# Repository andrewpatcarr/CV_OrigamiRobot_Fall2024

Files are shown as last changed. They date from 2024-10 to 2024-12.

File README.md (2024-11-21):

CV_OrigamiRobot_Fall2024
---
---

Repository for Fall 2024 ME-400 (Special Problems for Advanced Undergraduates)
---

- Currently, focused on computer vision object detection and redesigning the origami worm robot.

- log.md has record of what I was doing on a particular day but was started about 2 weeks into quarter.

- setup.md has some setup information for RealSense 2 and YOLO

- Programming has some scripts for using RealSense, cv models, training and testing, and controller for robot

- CAD has the origami robot assembly, some other SolidWorks files, and STLs for 3D printing

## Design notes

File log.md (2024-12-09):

Logbook
---
---
12/08/2024
---
- created wiring diagram

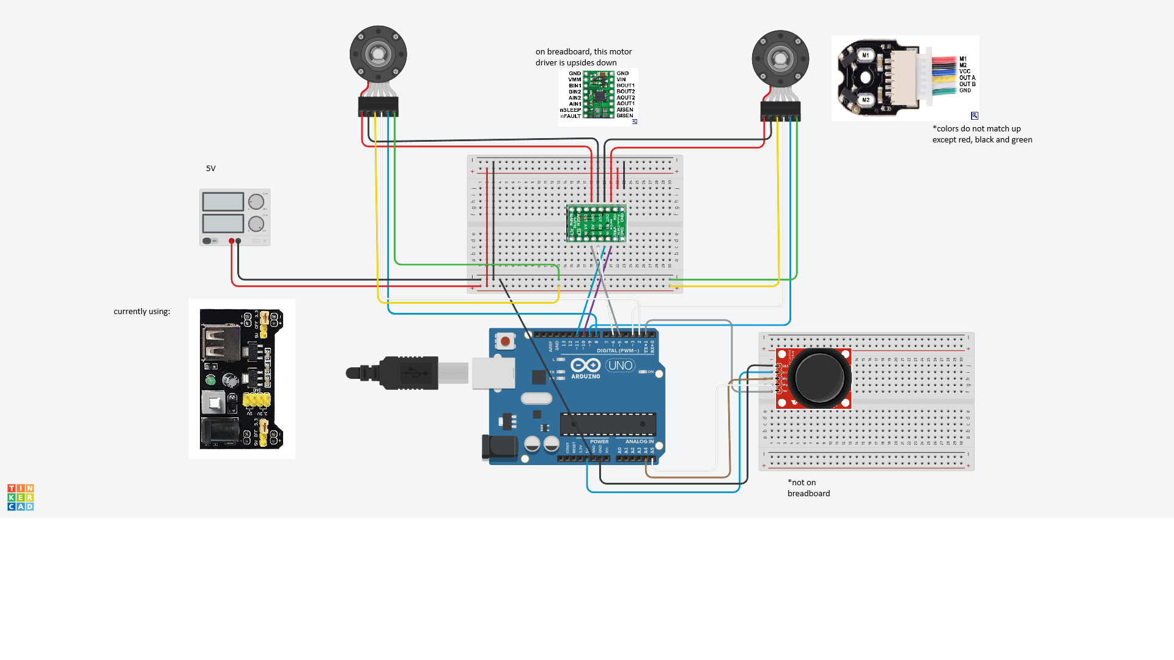
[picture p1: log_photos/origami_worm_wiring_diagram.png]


- created bill of materials
- wrote up assembly instructions
- pretty much done with [report/documentation](Origami%20Worm%20Robot%20Report%20and%20Documentation_FALL24.docx), might comment on main program

12/07/2024
---
- working on report/documentation
- had to fix some paths for images on log that got off because I reorganized some files
- tried new pad, pretty sure it is 25 degrees at 4 mm height. Works really well on carpet, going to try on rough outdoor surface

[video of robot on carpet](https://cpslo-my.sharepoint.com/:v:/g/personal/apcarr_calpoly_edu/EZ3gfSpz0YdHlWizx2pAg3gBb_xeV1YFyOWcL83Z5IEy0Q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)

- works on rough surface relatively well. Better than before for sure.

[video on standard garage concrete](https://cpslo-my.sharepoint.com/:v:/g/personal/apcarr_calpoly_edu/EVyeC1qBWZ9LjJJ2trlWG6QBVoEVjFBpGhsD8ZwvbOOz0Q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)

[video on rougher more irregular concrete](https://cpslo-my.sharepoint.com/:v:/g/personal/apcarr_calpoly_edu/EYgH6j8teHZAugXCq2LXksoB2CPt29aTcvvlFOFw1zrG9Q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)

- one thing i realized during testing: there is a balance between angle of the pad, the stiffness of the teeth, and the surface. This balance changes the performance. if the angle is very small, the teeth won't grab. if the angle is too large, the teeth won't grab. if the teeth are too weak, they will just fall down and not grab. If they are too stiff, they will not grab. A rougher surface seems to always be a good thing. Should try on sand paper to see

12/06/2024
---
- working on report/documentation

12/03/2024
---
- going to test more angled friction pads. Previous ones were at a 40 degree angle. New ones are 30 and 25. I am also make these longer. Previous were 3 mm tall, new ones are 4 and 4.5 mm tall.
- these should be less stiff and should deform and work closer to how we think they should
- the auto-orient showed me that I can print them standing up in a different way than I was thinking. I am putting 1 layer of raft because I feel it'll be unstable. Since I can print it this way, I am going to try 15 degrees. I had to reduce the amount of teeth from 6 to 5 for this.

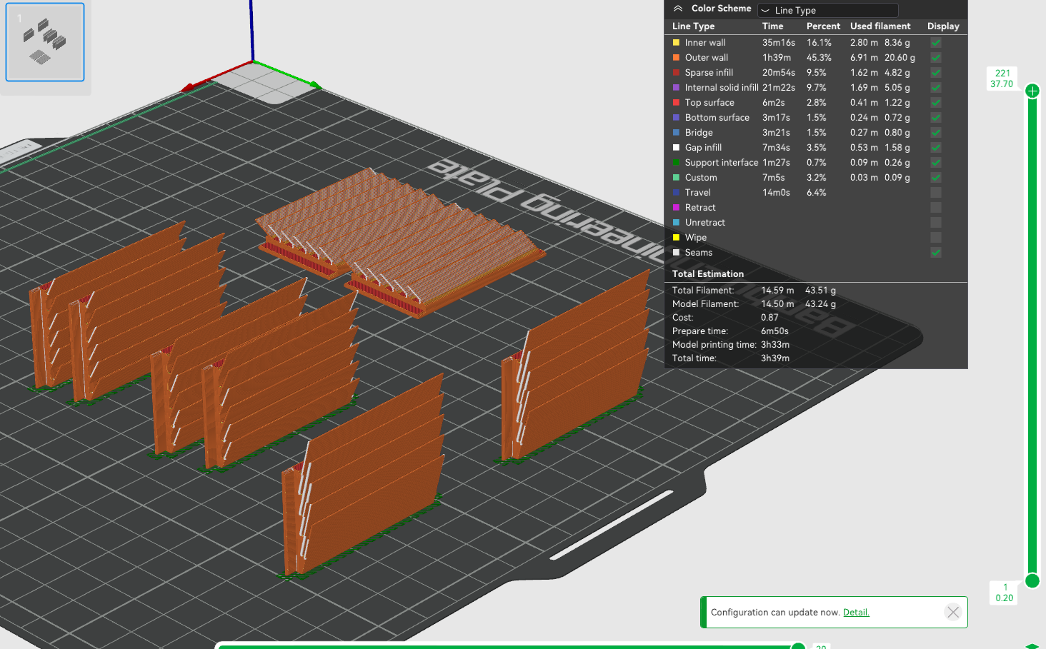
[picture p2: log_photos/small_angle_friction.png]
small_angle_friction


11/28/2024
---
- from last meeting, motion seems to work better with short and fast compression cycles. This is when the robot sits more flat but has torques curling the robot into the ground.
- The robot often gets stuck on one pad, but a max compression can sometimes set it free
- this [paper](https://ieeexplore.ieee.org/abstract/document/6266749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)
uses a single leg friction pad similar to our design. I think we could use something similar with longer legs as they will be much flexible and can deform how we want. 
- our motion is called peristaltic
- more worm angle seems to be cancelled out with less friction pad angle. So with a very large worm angle, we could have less worm angle and vice versa. Depending if we want less caterpillar like motion
- [OSCAR](https://www.ideals.illinois.edu/items/118254) uses a small locking wheel to get directional movement

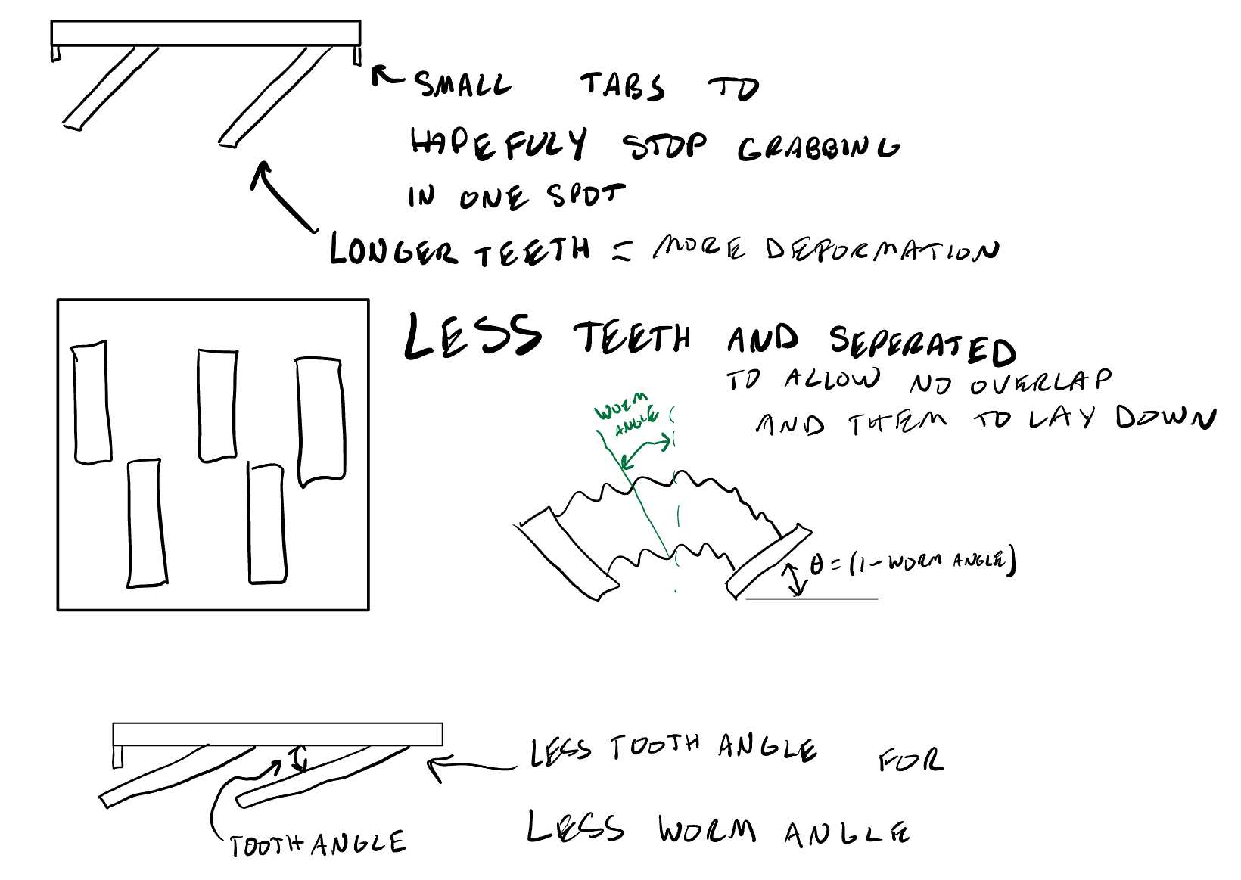
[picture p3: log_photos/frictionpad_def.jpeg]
frictionpad_def


11/20/2024
---
- new controller works very good, normal compression and decompression works smoothly. The controller also makes it easy to adjust one motor on the fly which also allows turning motion. It is up to the standard to complete reliable tests.
- tested it outside again, worked about the same as before --> not well. The surface was somewhat uneven but it looked more like the friction pads were not working as designed. The robot being so light allows the wires to make some impact. I tried to reduce it as much as possible but it is hard with stiff wires.
- I tried lowering the anchor point of the tether, and it did not make much of a difference. The friction pads definetly work in creating friction but one pad dominates and won't move either way. Or the pads will be at a similar friction force which makes both sides slide during compression.

Current motion cases:

1. compression --> both slip --> decompression --> one holds slips slightly less than other --> very small amount of forward displacement
2. compression --> one holds, other slips --> decompression --> same one holds, same one slips --> no motion

I see two possibilities for these problems:
1. theoretically sound for forward motion but very hard to create in the field
2. fundamentally and theoretically flawed for forward motion

- Directional friction is sound so I think it is likely that this would work if perfectly implemented, but is just very difficult to mitigate all the negative factors
- For the gecko pads, the implementation and overall movement may need to change. Similar to how an inch worm moves, a lifting, moving forward then planting approach would be ideal. It will be hard to actuate and move one side at a time. We don't have a way to only move one pad a time without directional friction.
- controller with no delay does not function. I am pretty sure this is do limitations of the motor driver. 

11/18/2024
---
- wrote new velocity control as shown in flow diagram [origami_joystick_control_DC_vel.ino](Programming/Arduino/origami_joystick_control_DC_vel/origami_joystick_control_DC_vel.ino)

11/17/2024
---
- Created flow diagrams for current control method (positionally) and for possible new method (velocity with alignment checking). Also created a flow diagram of how the x,y is decoded for straight motion and turning.

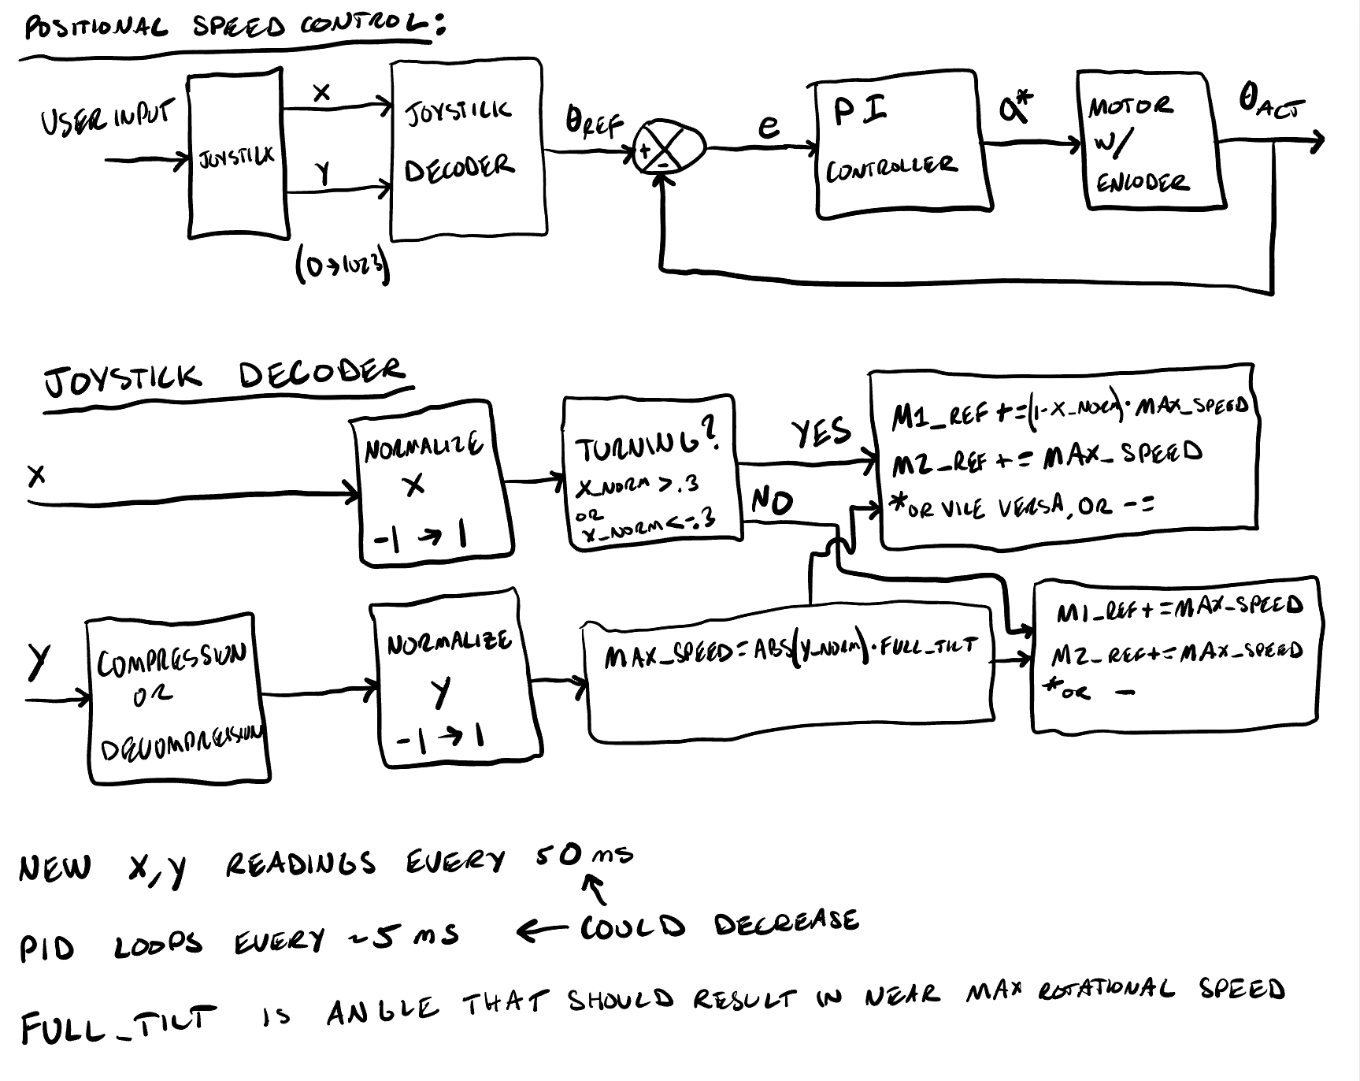
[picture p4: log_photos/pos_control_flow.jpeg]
pos_control_flow

vel_control_flow
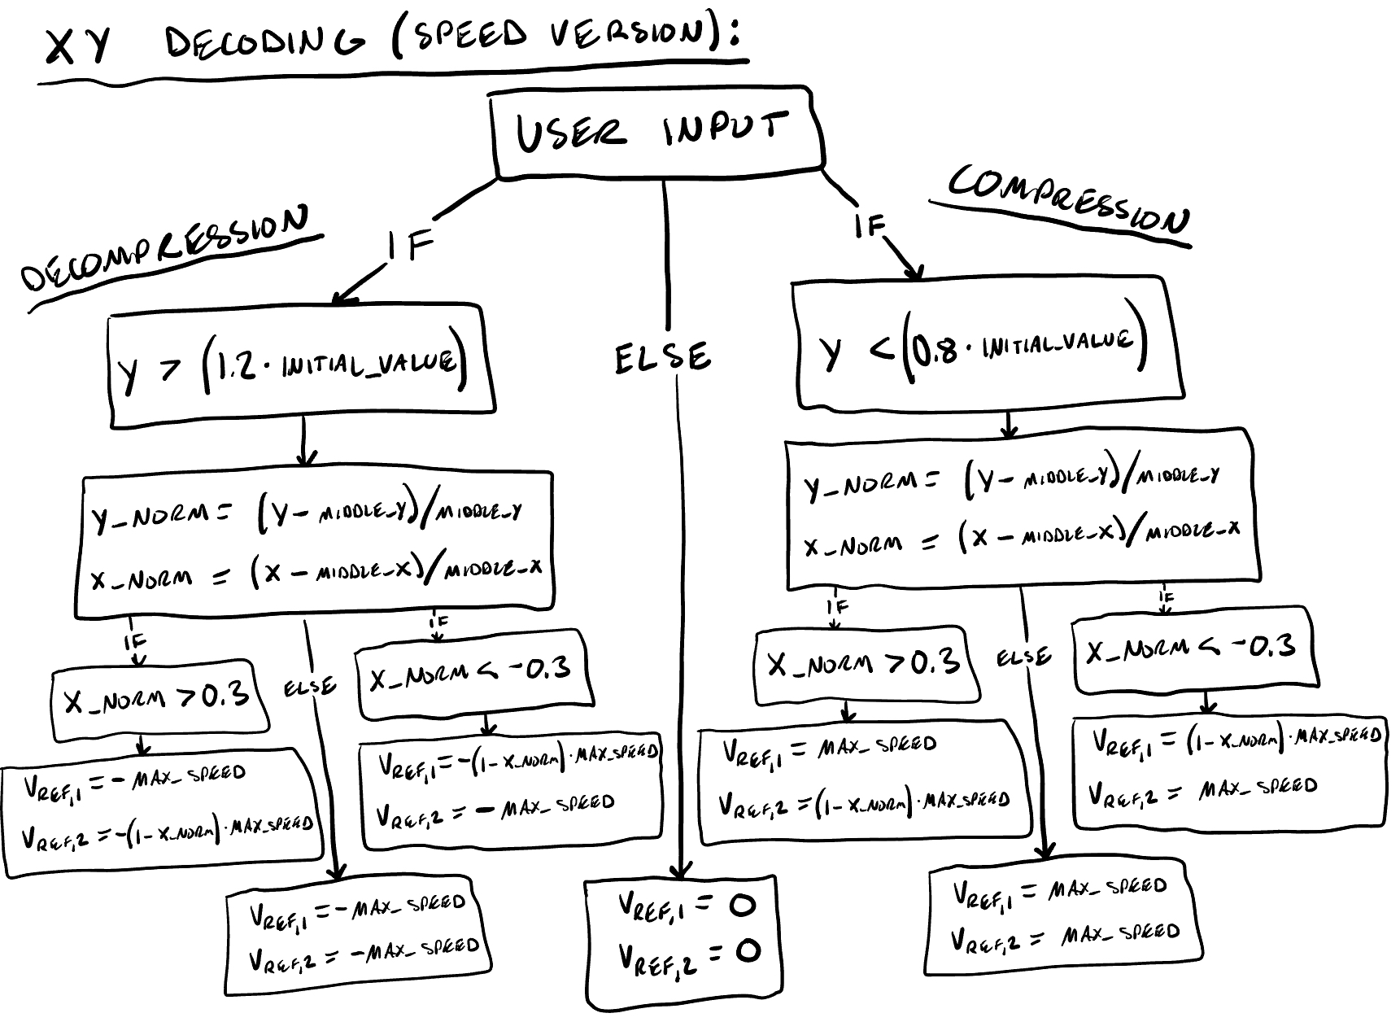
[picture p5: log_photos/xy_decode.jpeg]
xy_decode


11/15/2024
---
- worked out bugs enough for compression/decompression based on the joystick movements. Script for that is called origami_joystick_control_DC_pos.ino
- created new script for adjusting each motor independently based on joystick x and y

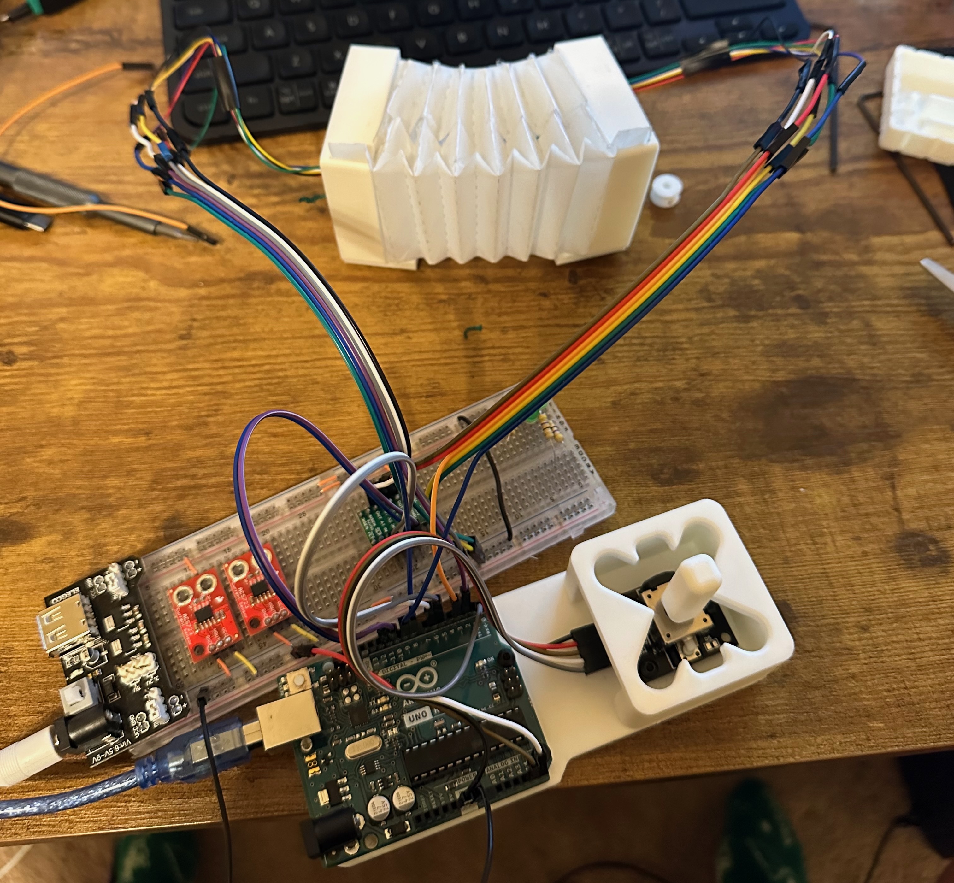
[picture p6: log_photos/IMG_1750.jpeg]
overview_photo

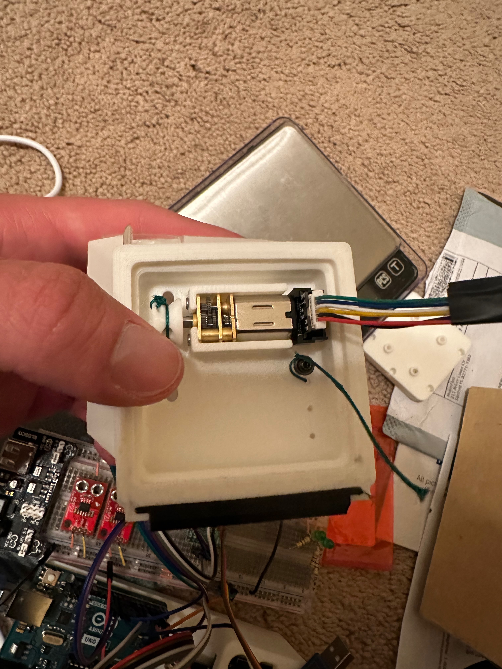
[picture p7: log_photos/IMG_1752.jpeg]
dc_motor_in


- going to test outside
- [video link](https://cpslo-my.sharepoint.com/:v:/g/personal/apcarr_calpoly_edu/EZbizppu2DRNnodf83J_MKYBdXKjzsVXct3wO4nJTWKWEA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). 
Increased worm angle seems to make movement possible again in the direction that the friction pads are designed for. The control is still not working great and you'll see it get off and jiggle during the movement. I think I need a combination of velocity and position PI control. Velocity for general movement and pos for reallignment after turning or if it gets off. 
- I think the next steps should be: get basics of controller working for reliable testing, try different worm angles, optimize friction pads

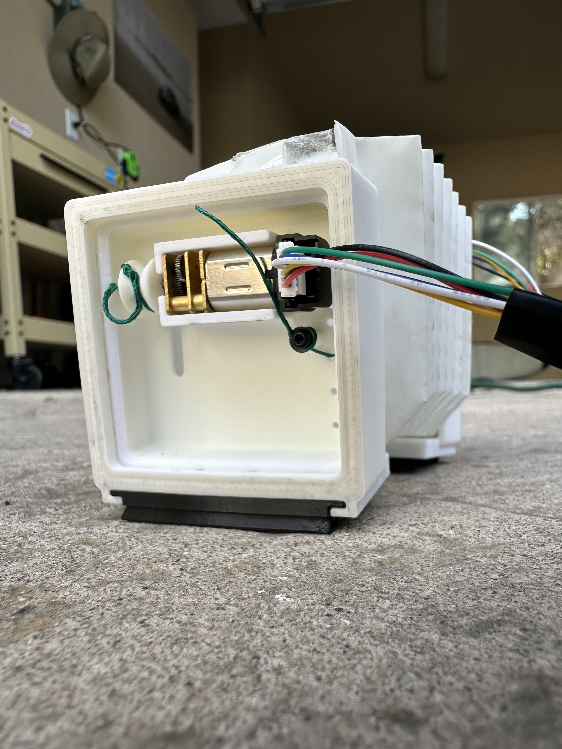
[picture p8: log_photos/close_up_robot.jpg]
close_up_robot


11/14/2024
---
- fully assembled rest of robot. Will update with more info tomorrow with some pictures. Worm motion is working better with lower hole attachment. Controller needs to be debugged for both motors and need to create a script for adjusting each motor independently
- new version is 97 grams

11/12/2024
---
- changed implementation on pid from velocity to position, differing speeds are made my adding degrees to the controllers setpoint then letting to try to go there for 20 ms. This method allows controller to control speed and direction well but needs to be adjusted and tuned. 
- I am going to add a feature that will align the motors back to the same angle position after a turn has been done or any time the x readout from joystick is zero. This will allow for ease recentering back to initial tension. 
- The controller needs to be tuned and the added degrees adjusted such that at normal full speed, the motors have space (in the form of PWM) to adjust and give power to one motor over the other in the case that one side of the robot has more spring force pushing back.
- made some final adjustments to the motor mount. Printing new ones that should be good to be mounted onto worm
- way to do line 2 above: function that checks if motors are out of sync, if compression then whatever motor is more negative in postion (or whatever the correct sign is). Then this function tells the motor to go to the other motors position and will continue to do so until gets within some amount of degrees. Then allow normal compression movement

11/11/2024
---
- soldered 22AWG wire onto JST wires so they could be pressed into breadboard and other connections



- wrote new control script for PID speed control with a motor class for control by the joystick, origami_joystick_control_DC
- The code has a class "DC_Motor" that has all the functions other than the encoder. Tried to do timing with interrupts at first but was getting some weird problems so decided to do it a less efficient but less complex way. 
- debugged most of code; encoder working properly; forward and reverse work alone; having a couple weird problems. One of them is that the joystick will make a motor turn correctly at first, but then it won't allow the other direction to turn. This problem is independent of direction and works both way. I tried to add a bunch of print statements but could not figure out why it is doing this. 
- took a little bit longer than expected to write all this code, but I think it will allow more performance once its working. May need to change PID method if the current velocity control method doesn't work. I could do it by calculating a small step in postion, then using a postion PID to go to that step in a constant amount of time so bigger position step will be more speed.

11/10/2024
---
- first try at motor mount makes me think that we may need to use the m1.6 screws for a better fitting. Going to try to find some or order some.
- soldered headers onto motor driver
- redesigned motor mount for m1.6s and easier assembly with pulley on

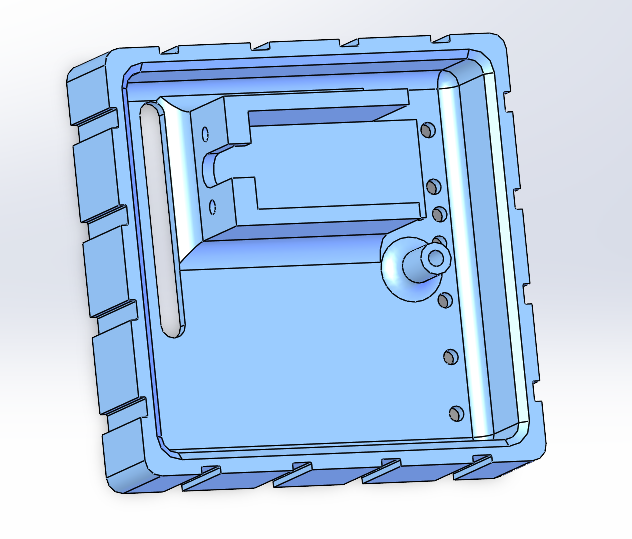
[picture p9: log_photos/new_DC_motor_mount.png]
new_DC_motor_mount


- designed new pulley for DC motor shaft

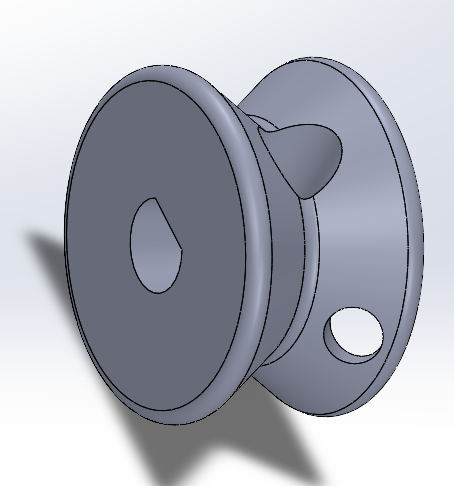
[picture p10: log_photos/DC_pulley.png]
DC_pulley


- fixed joystick/arduino board as was too tightly spaced
- received the JST SH connectors for motors
- printing all new components to test. Need to write new script for PID speed control of the robot to start. Might do some loop code once motion is working well.

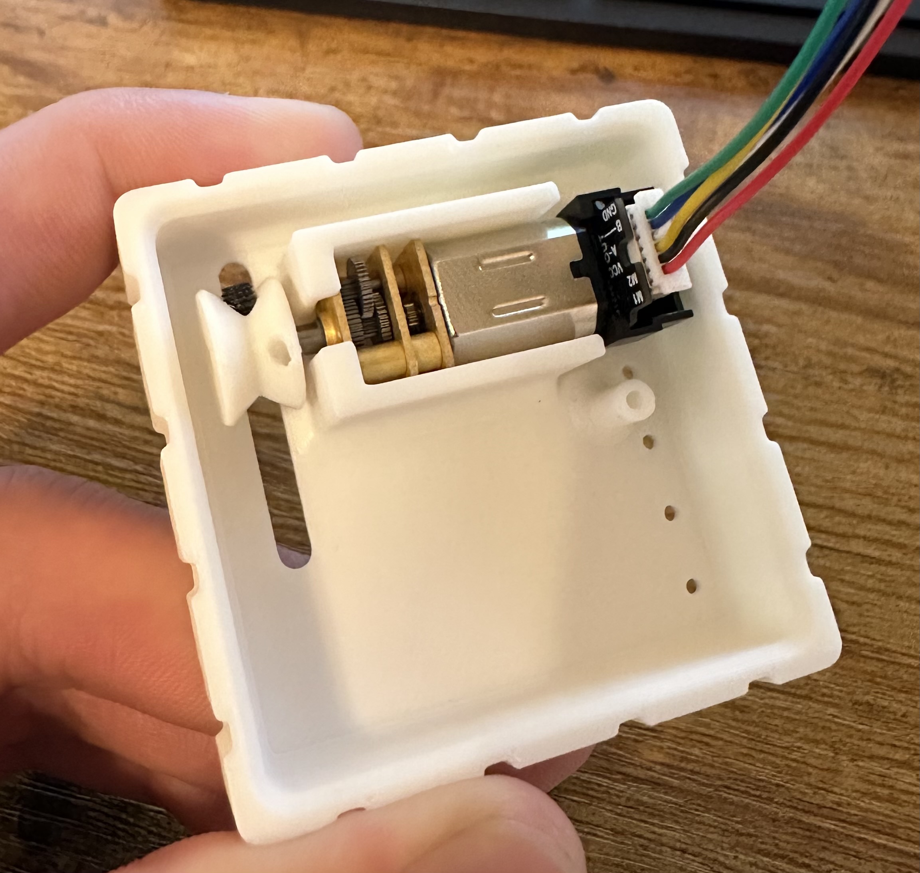
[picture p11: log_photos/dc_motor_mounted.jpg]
dc_motor_mounted


11/8/2024
---
- Last night, tested a bunch of new designs, thinner, thinnest and supersliced, which all did not work well. Although they did confirm that they are more frictioness than stiffplastic along so I think there needs to be a geometery that gets the friction pad out of the way rather than having a pure differential in friction.
- Here is the initial drawing idea: 

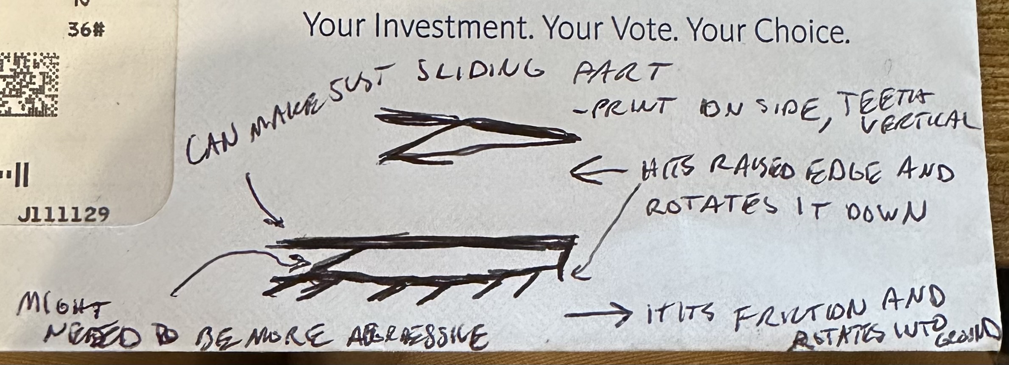
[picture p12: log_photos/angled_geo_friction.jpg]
angled_geo_friction


- And here is an initial solidworks creation of the geometry, but I think changes need to be made for it to work. The friction pad would be put on the left top surface:

angled_friction

- I want to try to create an extreme version of the supersliced (bunch of feet one) that has 1 mm feet and with stronger angles to replicate a form of backcountry ski skins
- Also, tried training for 50 epochs with data set and based on initial look into the data, it does not seem to have worked any better but did level off. Need to look more into it.
- [insert train 12 data and discussion]
- Designed a DC motor mount without screws, discovered it had m1.6s after and don't have any. If this idea doesn't work then I will get some screws. Going to print and test. 

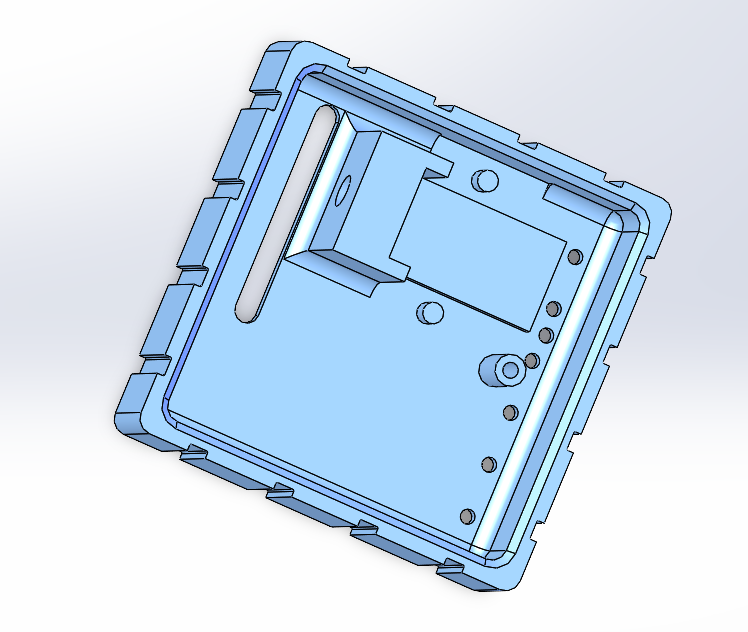
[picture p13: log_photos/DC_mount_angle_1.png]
DC_mount_angle_1

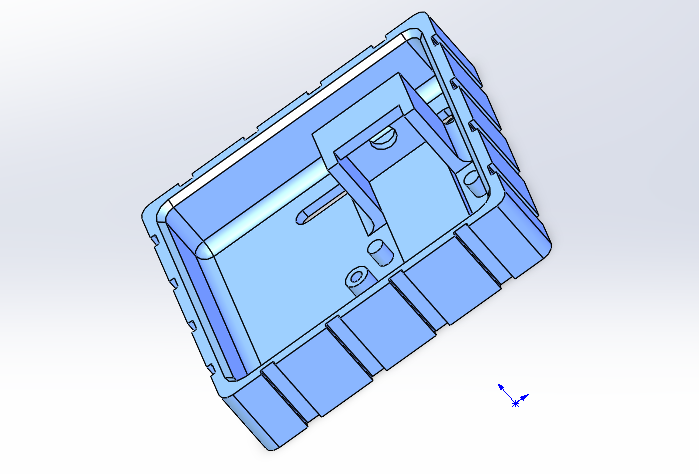
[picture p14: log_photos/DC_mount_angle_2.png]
DC_mount_angle_2

DC_clamp

- created a board that integrates joystick and arduino

11/6/2024
---
- drying the spool of tpu and going to print some new friction pads to try out
- got a pulley to work again, printed at .12 mm layer height; I'm pretty sure this means more precision on the teeth of the pulley
- read [research article](https://www.researchgate.net/profile/Kazim-Raza-5/publication/339640242_Fast_and_Accurate_Fish_Detection_Design_with_Improved_YOLO-v3_Model_and_Transfer_Learning/lin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)
but did not find much on how they did their transfer learning. It could have gone over my head, but it seems they just talked about the uses of it for this application. Here is a snippet from the short transfer learning section:

t_learning_snippet

- however, I did find that they trained their successful detection model for 100 epochs. I only trained for 10, and the training data makes it look like it was still steadily improving, but needed much more time. I think I will train it on the school computer for 50 epochs and see how that changes things
- going to look at more research papers to try to find some specifics on how they are implementing transfer learning
- started with brain tumor yolo-based model with transfer learning, but didn't say how they did it. They referenced [Deep Convolutional Neural Networks for Computer-Aided Detection: CNN Architectures, Dataset Characteristics and Transfer Learning](https://ieeexplore.ieee.org/document/7404017) (not on YOLO models) which mentions that they used smaller learning rates for all the CNN layers except the last. They say that "last fully-connected layer is random initialized and freshly trained, in order to accommodate the new object categories in our CADe applications"
 and its learning rate is kept at the original. They referenced [CNN Features off-the-shelf: an Astounding Baseline for Recognition](https://www.cv-foundation.org//openaccess/content_cvpr_workshops_2014/W15/papers/Razavian_CNN_Features_Off-the-Shelf_2014_CVPR_paper.pdf) for their method but they did not focus on object detection and were not using YOLO-based models.
- the default epochs for yolo training is set at 100, definitely think our model needs to be trained for more epochs
- from the last training, here are some plots showing the progression of our mAP50 and mAP50-95 (mean average precision for different levels of correctness) which show that it hadn't flattened out yet

train10_mAP_plots

- outside test with initial friction pads which are pretty thick: [link](https://cpslo-my.sharepoint.com/:v:/g/personal/apcarr_calpoly_edu/Ea4VjNevzMZMiXy5tFDmahABc4tGWjPi51OIGT4sImdVfA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)
. The speed controlled servos are battling different strengths of spring force and don't compress at same rate without manual adjustment to scales. DC motors will fix that problem. The friction pad in use does not flex much and did not work well. I'm hoping some of the new designs will work better which are all thinner
- doing a quick static loading study on solidworks to see how the model will deflect which I think is key to friction pad success. One side is approximately 50 grams. Didn't set up fixtures correctly, going to try again another time.

11/5/2024
---
- created some new friction pad ideas, going to print later and test if i can get a pulley to work on the servo.
- two are thinner versions of original. The rest of them are cut out designs based on the thinner version of current

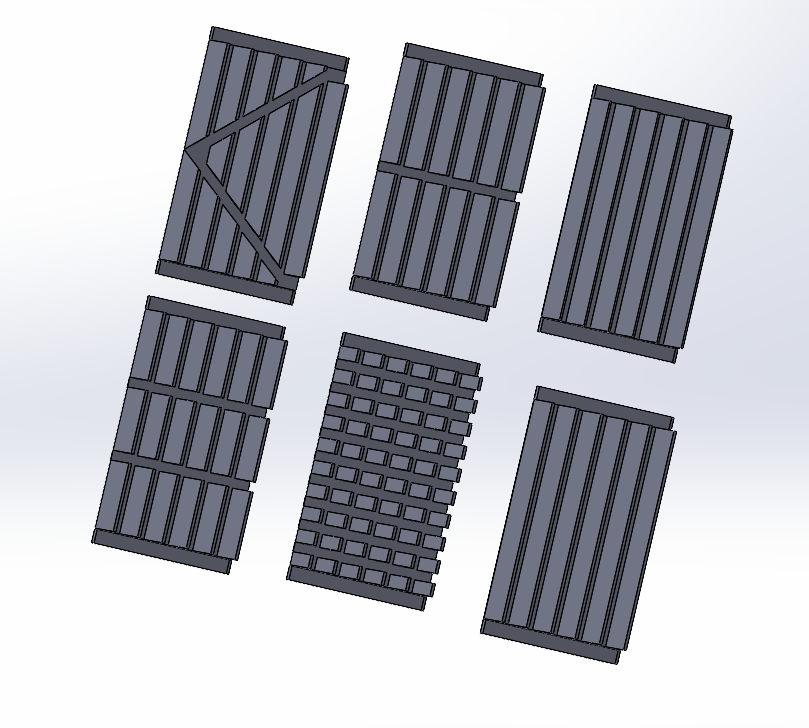
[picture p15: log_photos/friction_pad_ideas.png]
friction_pad_ideas


11/3/2024
---
- 10 epochs took 9.31 hours. Inference time went down significantly from 1 epoch train (~90 ms to 5.8 ms). As seen in table, the model only detecting robot arm in one of the photos. Most likely due to incomplete data and maybe not enough angles. Performance of other objects was decent considering this is far less images than full COCO dataset
- cleaned up wiring on arduino and current sensor as much as possible
- found a joystick module and created new script to control the worm using it. It allows pure compression/decompression as well as turning commands. Should make it much easier to test and use
- Looks like this: 

joystick_module
- going to design a base for joystick module and top so its easier to use and control
- base and joystick top created and being printed now
- made this joystick transmission thing so its easier to go dead straight and to a pure turn

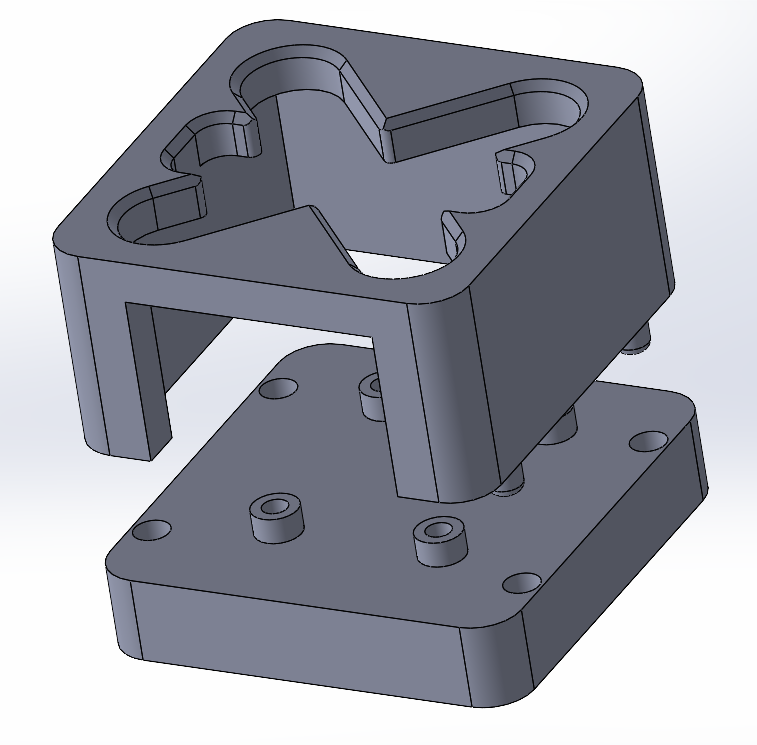
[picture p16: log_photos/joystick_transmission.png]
joystick_transmission


- transmission looks cooler than it actually works but still is good for guiding turn:

real_life_joystick_assem

Video of test:

[joystick_assem_test](https://cpslo-my.sharepoint.com/:v:/g/personal/apcarr_calpoly_edu/EaTgc_oRwHBKrTsXxgcHwpsBTS4aR1mzuO3mRuU0t0Zwog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)

<!DOCTYPE html>
<html lang="en">
<head>
    <meta charset="UTF-8">
    <meta name="viewport" content="width=device-width, initial-scale=1.0">
    <title>Image Comparison Table</title>
    <style>
        table {
            width: 100%;
            border-collapse: collapse;
        }
        th, td {
            border: 3px solid #ddd;
            padding: 8px;
            text-align: center;
        }
        th {
            background-color: #f2f2f2;
        }
        img {
            width: 300px; /* Adjust size as needed */
            height: auto;
        }
        .row-header {
            background-color: #f9f9f9;
            font-weight: bold;
        }
    </style>
</head>
<body>

<h2>Model Image Comparison</h2>

<table>
    <thead>
        <tr>
            <th>Image #</th> <!-- Empty cell for top-left corner -->
            <th>11s</th>
            <th>11n</th>
            <th>4 class custom</th>
            <th>COCO+Robotic-arm off 11s</th>
        </tr>
    </thead>
    <tbody>
        <tr>
            <th>1</th>
            <td>Model 1 - Image 1</td>
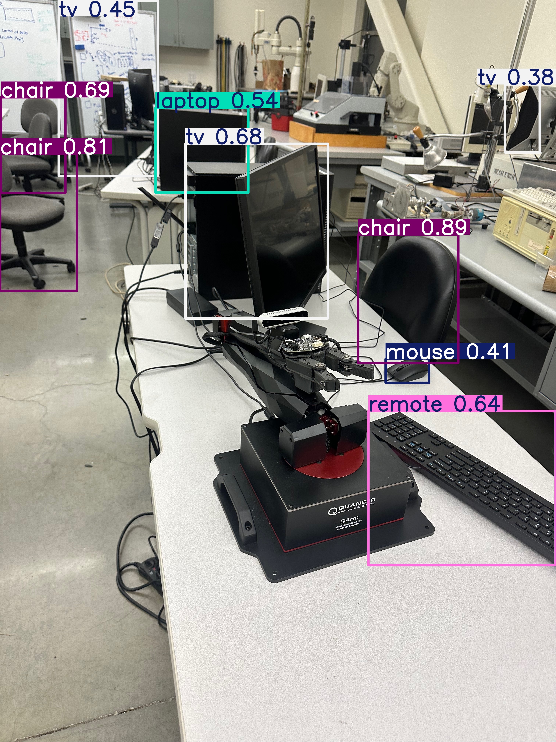
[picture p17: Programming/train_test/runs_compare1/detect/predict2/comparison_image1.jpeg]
Model 2 - Image 1
            <td></td>
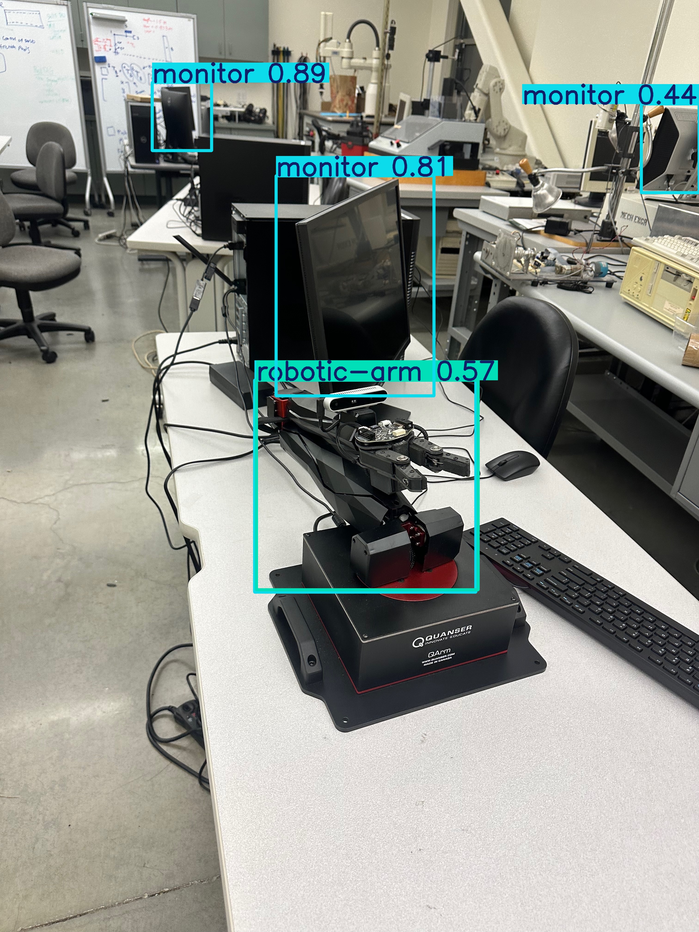
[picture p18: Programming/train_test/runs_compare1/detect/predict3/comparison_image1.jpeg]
Model 3 - Image 1
            <td></td>
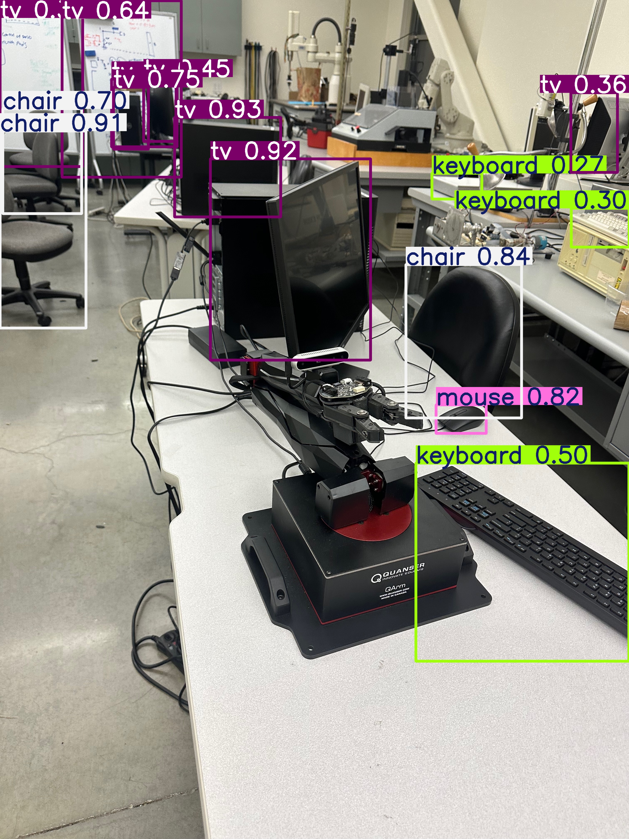
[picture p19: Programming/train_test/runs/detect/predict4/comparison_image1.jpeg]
Model 4 - Image 1
            <td></td>
        </tr>
        <tr>
            <th>2</th>
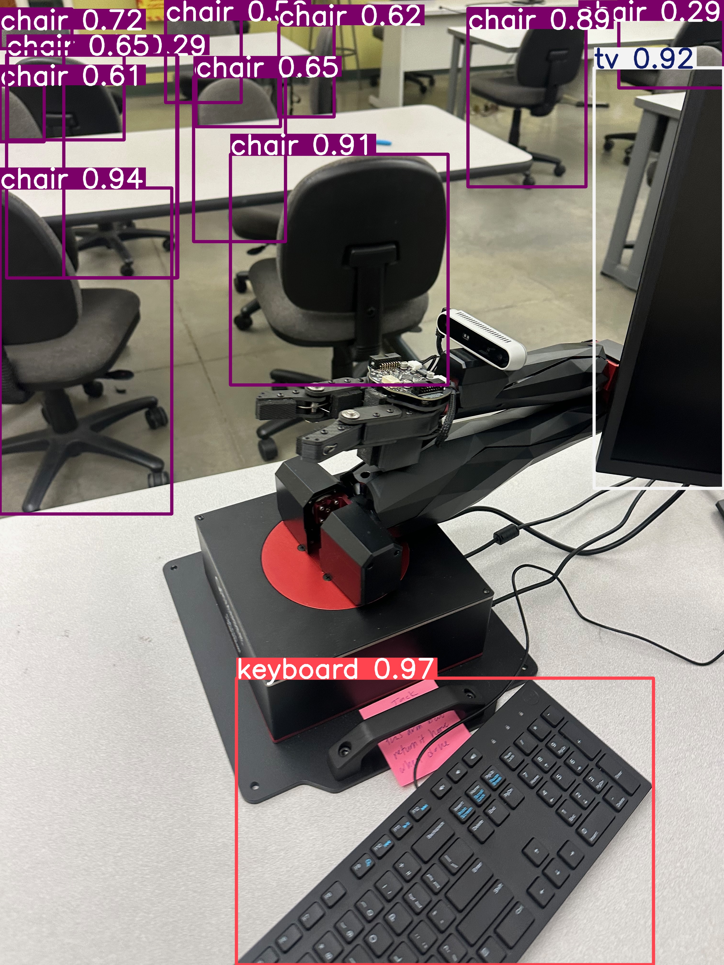
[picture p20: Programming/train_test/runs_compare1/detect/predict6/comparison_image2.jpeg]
Model 1 - Image 2
            <td></td>
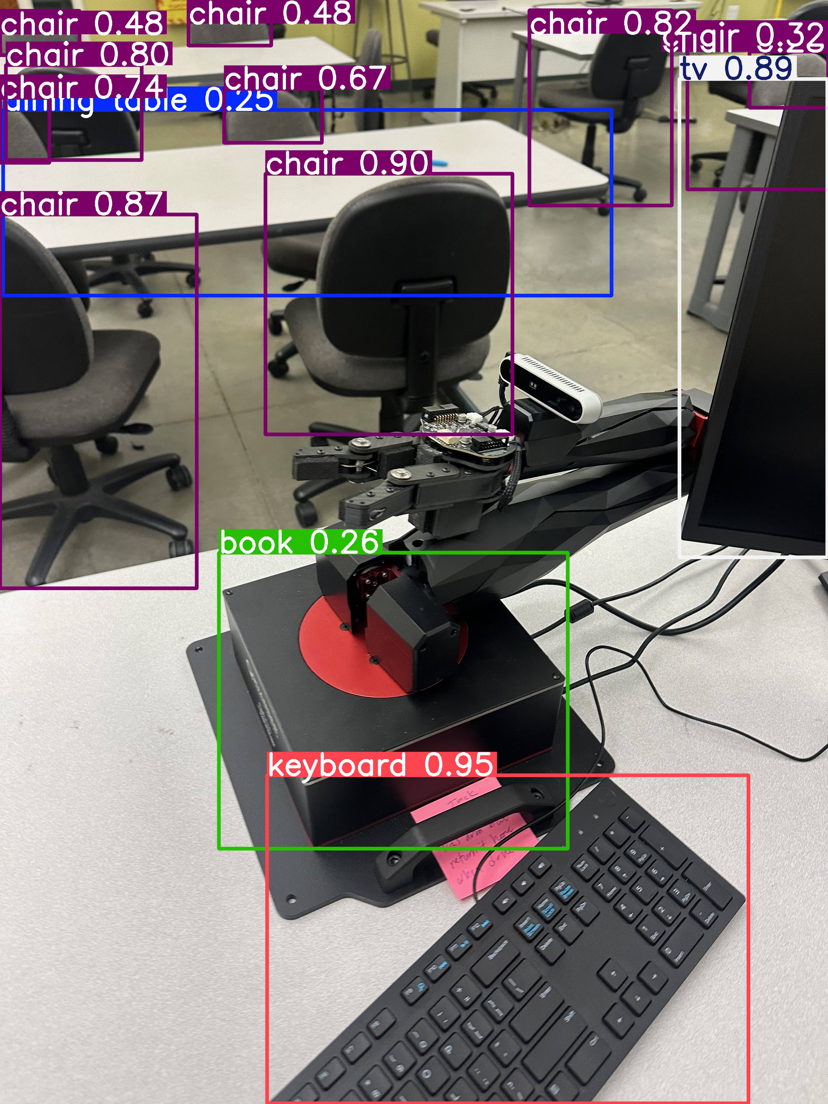
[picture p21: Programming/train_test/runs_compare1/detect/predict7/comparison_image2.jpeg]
Model 2 - Image 2
            <td></td>
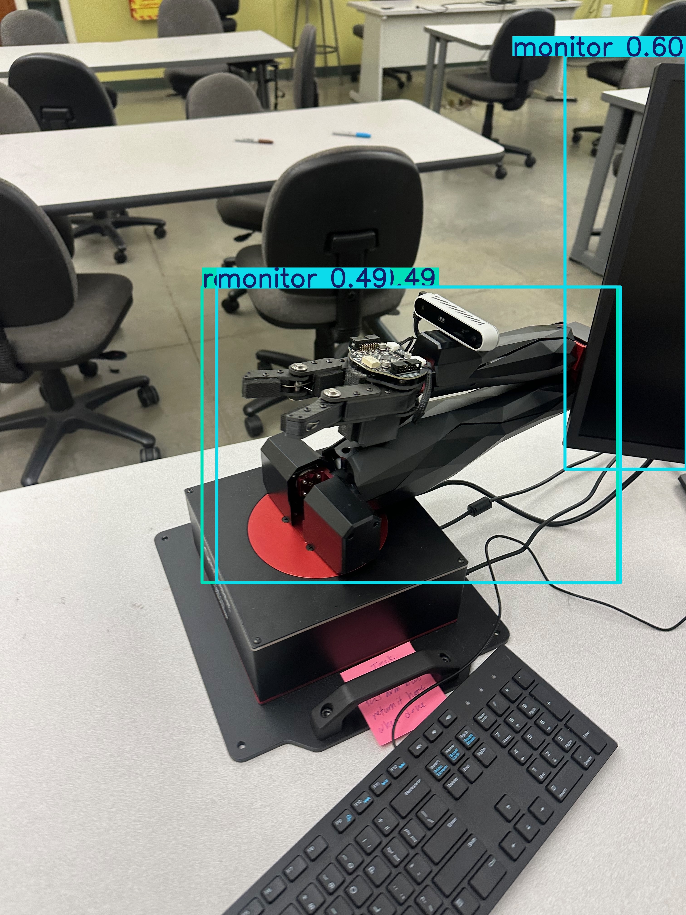
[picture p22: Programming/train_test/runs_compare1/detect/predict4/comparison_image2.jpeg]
Model 3 - Image 2
            <td></td>
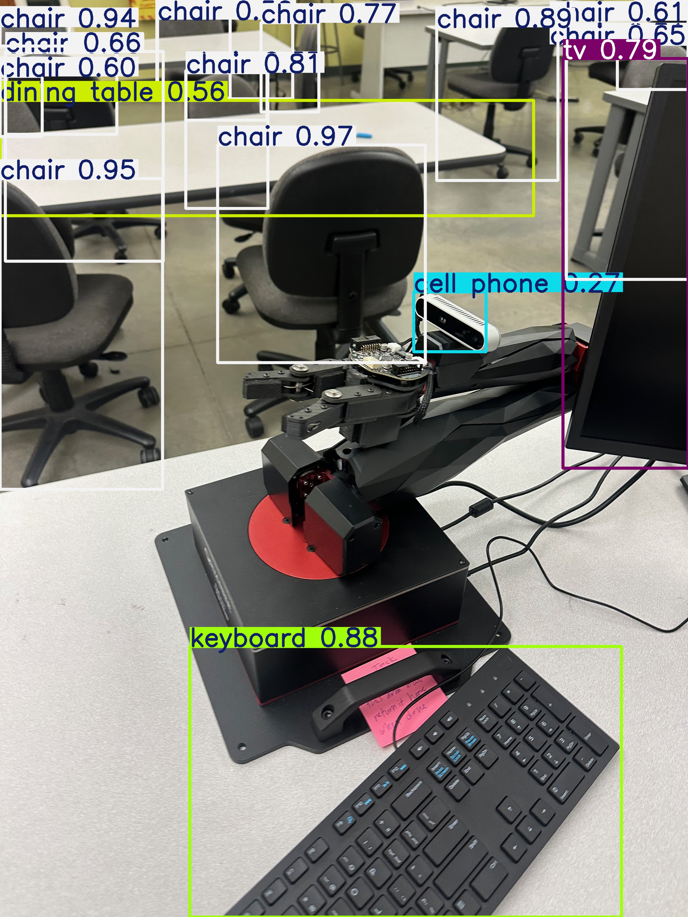
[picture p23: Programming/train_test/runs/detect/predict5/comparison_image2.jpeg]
Model 4 - Image 2
            <td></td>
        </tr>
        <tr>
            <th>3</th>
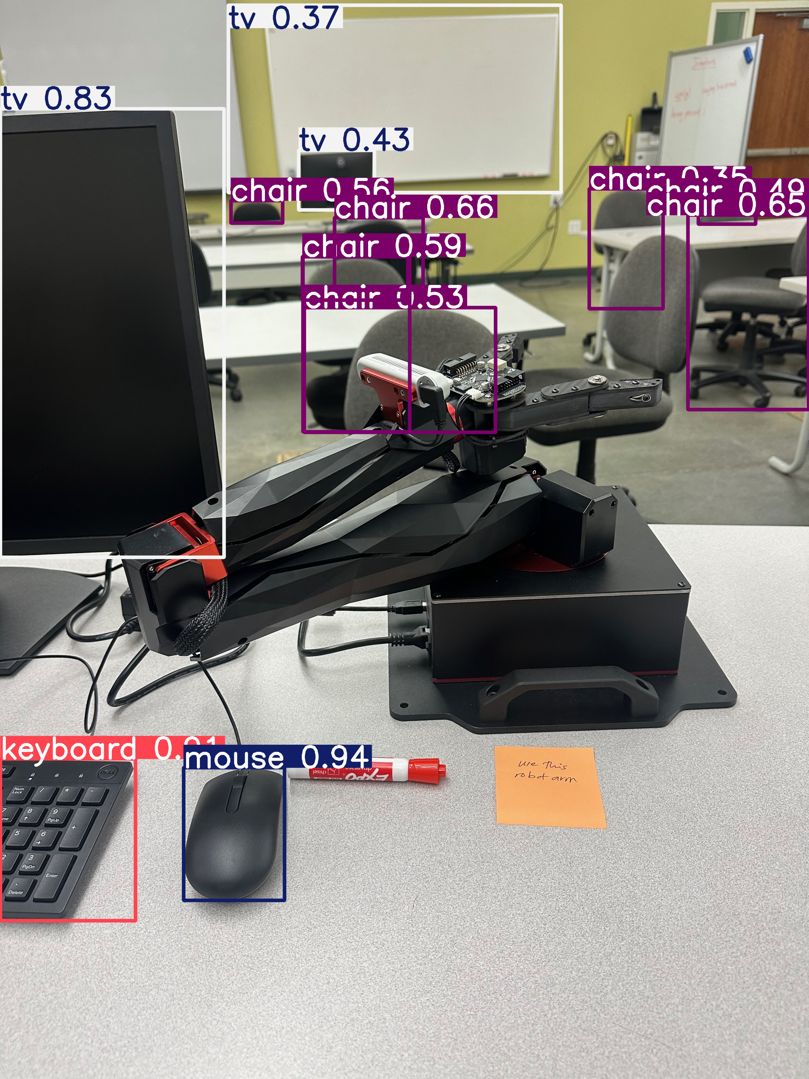
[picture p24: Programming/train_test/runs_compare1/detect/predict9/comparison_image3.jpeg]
Model 1 - Image 2
            <td></td>
            <td>Model 2 - Image 2</td>
            <td>Model 3 - Image 2</td>
            <td>Model 4 - Image 2</td> 
        </tr>
    </tbody>
</table>

</body>
</html>

11/2/2024
---
CV stuff
- going to label new robotic-arm photos to finish rest of the dataset; added 101 photos with robotic-arms in them
- new dataset has 81 classes, 20413 photos for training, 1982 for validation, 990 for testing after augmentation
- going to train model from scratch first, then freeze train with same dataset to get an idea of time and quality differences
- ran a training for only 1 epoch to get a sense of how long it will take to train, and how good 1 epoch will train the set. Looks like its going to take roughly an hour. At home, there are 1274 iterations per epoch at 8.5G of GPU mem.
- with 1 epoch (train9), it did not recognize the robotic-arm, I'm going to train for 10 epochs overnight
- it says this when the training starts, so I think it is automatically doing freeze training when a model is inputted as part of the train command:

freeze_training_maybe

Only referring to the top two lines in screenshot

this is the code I used for this

    yolo task=detect mode=train model=yolo11s.pt data=COCO_robotic_trainingset\data.yaml epochs=10 imgsz=640 device=0

10/27/2024
---
CV Stuff (since a lot written about both sides of the project today)
- coco dataset upload failed on roboflow, need to delete whole project to upload more photos with free plan
- Tested friction pad with robot on carpet, worked for a second but then got stuck with the back sliding back and forth. The pulleys keep slipping, I think it would be worth it to switch to DC motors. Also, thought of an update to the pulley so that the thread won't come off when there is not tension. Going to make it enclosed where the pulley is
- Uploaded dataset to roboflow again, but it looks like they don't have the correct annotations again. Uploading them and going to see if they do after uploading. If not, might need to find a different dataset. Either way, I am going to try to freeze train with other dataset with limited classes and see if it keeps COCO classes
- Annotations did not work
- Did some more research into freeze training on newer models of YOLO. Most of the information on freezing layers and retraining final layers was for older outdated YOLO models. Now that you can just pip install ultralytics and have everything you need to use new YOLO models, its different to freeze layers and train. Going to keep looking into it
- in the "[train](https://docs.ultralytics.com/modes/train/#train-settings)" documentation, there is an argument "freeze" that freezes the first N layers of the model by index. I should be able to use this for our purpose, just need a good dataset
- looking at this [discussion](https://github.com/orgs/ultralytics/discussions/3862), it should be possible to do freeze and then train. One ultralytics moderator said that it is not completely necessary to freeze the backbone to add classes to coco. If i can get a good coco 10k or 5k dataset, I should be able to try both of these. Some of it is still quite confusing on how to actually do any of this successfully.
- found [this](https://www.kaggle.com/datasets/bardiaardakanian/mmsample?resource=download) 5k dataset which (if it works), should be good enough for testing if freezing works and is useful
- Going to make a new dataset of robotic-arm oriented photos and label with COCO labels and then robotic-arm

Worm Robot Stuff
- printing new pla pulley; if doesn't work, I'm going to look into small geared dc motors with encoders
- pla pulley had better teeth connection this time, used a different, longer m2 bolt that threads in better and locks better; going to test movement
- put dataset into roboflow, looks like it has labels this time, but it ended up being 10,000 images because there were 5000 for train and 5000 for validation. To add robotic arm photos, I'll need to delete some of the images unless we upgrade our roboflow plan.
- Looking at small geared dc motors, need to be <40mm in full length to fit. Center of pulley needs to be around 37 mm from far side of servo mount. This [one](https://www.amazon.com/dp/B07FVRL4SW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) is a possibility.
  The one linked is 500 rpm  with .15kg-cm rated torque. According to [this](https://www.amazon.com/FEETECH-Continuous-Rotation-Helicopter-Airplane/dp/B097SZQ4CH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), the current servos only provide stall torque which is 1.5 kg-cm.
- Thinking if we are to get better motors, we should also try to maximize performance for future changes and use cases
- Quick calc for required torque with pulley diameter: 

motor_torque_calc

(if this is too small, it is [here](log_photos/motor_torque_calc.jpg))

- after that calc, the motor does not need anything close to 500 rpm. Under 60 will be good (future extra speed); should allow for a very high torque but small motor
- there are many good dc motor options (like [this](https://www.amazon.com/Hilitand-Brush-Geared-1218GE%E2%80%91N20-Reduction/dp/B08LLCL97S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), but getting one with an encoder is difficult. May be able to use an optical speed sensor but could be difficult to incorporate
- [This](https://www.amazon.com/dp/B07N18S3M3/ref=twister_B0BPM11WG6?_encoding=UTF8&th=1) looks good, but has no information on torque, pps, or dimensions so pretty sketchy
- A potentiometer type encoder could work but unsure if something like [this](https://www.amazon.com/uxcell-Encoder-Digital-Potentiometer-D-Shaft/dp/B07R9LSWTP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) is continous rotation or not
- Pololu makes high quality motors, used some for internship. This [one](https://www.pololu.com/product/5147) is geared with an encoder. It has a no-load speed of 73 rpm and a stall torque of 2.4 kg-cm. They are more expensive than other ones ($26). This is one of the medium power options. They have some that operate at higher power and lower power. The motor will fit well in the casing. 
- There will be 6 wires for each motor then which will impact the performance if they are going directly to the arduino. A possible solution would be to use one chip to do all the work with the encoders and just send an angle value to the main microcontroller. 
- Idea for fully contained, WiFi enabled future design for robot: 

origami_concept

- ideas for components within above design: [6V battery](https://www.duracell.com/en-us/product/ultra-lithium-223-battery/) that will fit, [Pi Pico](https://www.amazon.com/Raspberry-Pre-Soldered-Microcontroller-Development-Dual-Core/dp/B08X7HN2VG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) that will fit, 
- above design does not have motor drivers; they would fit near each motor relatively easily or even just one for both on the side with the pico. A dual motor driver like [this](https://www.robotshop.com/products/pololu-drv8833-motor-controller-2130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) would be good
- custom pcb would be ideal in the far future of iterations
- Improving the strength, ability to control, and quality of the design and prototype is important so that multiple techniques for increasing performance can be tried (ex. varying speed of compression, controlling differential tension).

10/23/2024
---
- adjusted thickness of friction pad slider to 1.2 mm; tested and it was too thin; put it to 1.3 mm and tested; tight fit but still easy to get in, could be a hair too thin but for the strenfth of the servos and expected friction, it should be fine
- going to test on the arduino
- in the future, changing to dc motor with encoder, motor driver could increase performance drastically; especially for speed and accurate rotation
- in testing, one of the pulleys started to slip where the teeth connect. Going to try printing it out of nylon
- did some of a csu training i need to do
- nylon gear did not print accurately enough to have teeth; going to print another pla one for now
- 10k dataset uploaded to roboflow but none of the photos have annotations. Might need to reupload to roboflow again, cause it took a while and I went to sleep before
- going to get a test photo going, might get a better one from lab with many photos tomorrow

code used:

    yolo detect  predict model=yolo11n.pt source='"C:\Users\Andrew Carr\Downloads\CV_OrigamiRobot_Fall2024\Object Photos\comparison_image2.jpeg"'

10/21/2024
---
- all robot structure parts printed; assembled it from scratch in about 35 minutes; everything seems to be in right order
  
- the plastic threads of the servo horn screw seem to be stripped on one of the servo which is partly how I tighten the thread into place. If this reoccurs as a problem, I may need to redesign
- going to print the new tpu pads to see how they work/fit into mount

10/20/2024
---
- all parts printed, going to assemble robot
- when trying to put clamp on, discovered that I didn't change the outer diameter dimension of servo mount so did not work; fixed it and printing new one, which will be an hour
- tried to get smaller cocodataset but some of the options that were posted would not download for me; going to keep looking
- Tried to download from this [repo](https://github.com/nightrome/cocostuff10k?tab=readme-ov-file) which I think it legitamate but outdated
- trying to download from this [dataset ninja](https://datasetninja.com/cocostuff10k#download) but wasn't working in a similar way to the above repo but can install from a python package so trying that.
  Above did not work, python script showed I was missing package but I followed instructions on website and didn't mention anything about it
- Dataset ninja download for supervisely format dataset worked and Roboflow can take supervisely formatted files
- Uploading to roboflow but learned only allowed to have 10,000 total so have to get rid of about 300. Hopefully doesn't make some of the annotations not work. Looks like it might take a bit, roughly 4 hours
- another error on the position of the tabs of the servo mount. Confident I fixed this time by making assembly in solidworks of actual pieces instead of test pieces. Going to reprint
- fitment test looks like this: fitment_show
- this is what it looks like assembled in solid works (except servo is actually rotated 90deg so need to fix mates): assembled_1

10/19/2024
---
- Print failed last night, pretty sure it was a surface grip problem but so going to reglue and try again
- found an error on my pulley part that may have made the print fail; I changed a diameter that another was based on but didn't update other side
- new way for attaching thread to pulley works very well; struggling to print out the teeth good enough to properly attach to servo
- trying some smaller outer diameter of teeth section
- trying to download a smaller version of coco to try transfer learning based on this [tutorial](https://github.com/ultralytics/yolov5/issues/1314)
- need to combine custom dataset with new object; curious what will happen if i have more than one of the same class
- new outer tooth diameter worked, 4.7 mm. Pulley system seems like it will work well
- updated servo mount to be stronger and fit the servo better: new_servo_mount
- adding a screw into place method for tightening other side of thread to servo mount

10/18/2024
---
- original idea for friction pads did not work as intended, pulley printed was too tight of tolerances for hole and connection teeth
- some new ideas for both of those: put hole through center of pulley section so I can pull thread through and put screw in to lock it into place
- for the friction pad: Create a way to just slide it in but have the friction pad be extra thick so only friction pad part will interact with ground
- going to cad it up
- new pulley: new_pulley
- new friction pad mount on clamp: new_outclamp
- new friction pad, trying to make ridges stronger, and new clamp system: new_frictpad
- increased inner wall dimension on clamp to make it a little easier for it to clamp
- going to print and test

10/15/2024
---
- working on 3D printable servo horn pulley; found cad file of servo on internet; designed horn off of other shaft
- here's what the first edition looks like in solidworks, also cut out a slot so servo will sit properly
servo_pulley_one
- printer can do resolution pulley_print
10/14/2024
---
- went to lab to test and saw that the springs edges are not just squares,
  there is a flat fold sticking up on top right/left of the robot,
  will need to adjust design
- going to bring robot home so i can design things for it better
- though of better way to connect friction pads using the flexibility of tpu
- tpu friction pad print went well, much more flexible but maybe too much
- looking at windup system on the servo for cable, needs to be better and I have an idea in mind;
  I think its important that the mechanisms for the robot are well designed so that proper testing can happen,
  hard to trust results when many other factors could be affecting results.
- measuring mylar with verniers shows a thickness of 0.4mm; currently printing new version with slot but spacing might be too aggressive
- added new way of sliding friction pad into place, then realized that I could now have the friction pad be more centered under the mount;
  might increase friction and performance
- fit test worked with walls; pretty tight but gives it a much more stable feel and look; allows the origami spring to only act as spring and not interact with ground
fit_test_walls
- printing updated clamp and servo mount to reassemble robot; once this print is done, will print friction pad that will fit in new system

10/13/2024
---
- starting redesign of origami robot structure and friction pads, need other parts to function better to properly test and get better results
- going to try printing pads in tpu, also new idea for a one way leverage mechanism that will press into ground in one direction
- trying new way to connect spring to mount, basically a press fit piece that will go around normal one and press fit the spring in
- this might allow for better connection and integration of the friction pads
- getting weird error in solidworks that the piece can't face or plane but won't show me where so hard to fix. Part looks fine so going to ignore for now
- going to create test piece for testing fitment
- printing at home out of pla, about 30 min, some parts of design look a little thin, but we'll see
- going to get my tpu ready to go to try printing out of that, needs to be dried for 24 hours at 50 degC before I can print
- from looking at print, thicknesses and size of walls and teeth need to be increased
- looking at paper to try to find thickness of mylar, will probably need to go to lab to test properly, did not find thickness
- going to work on one way friction press mechanism
  new_friction_idea
- fit test worked pretty well, might need to try some different spacings, new version will be stiffer too
  paper_fit_test
- printing new version (larger teeth, thicker walls, filet on corner) and going to test with mylar spring, 32 min print, pla
- here's what the new clamp design looks like in solidworks new_clamp_solidworks
- new test piece did not fit together well, some parts were too tight, giving it more clearance and going to try again
- pretty sure problem was that the extra clearance given was only going to one side since location of tooth dimension was on one side, 
  so adjusted location such that it has .2 mm clearance on each side
- giving .2 mm clearance on each side of tooth, .4 mm at top of tooth; 
  outer diam of inner clamp is 52.78 mm, inner diam of outer clamp is 53.5 mm ~~ .75/2 == .38 mm clearance between clamp
- in the worm assembly, lined up the clamps to make sure everything looked right, found that the teeth were not alligned correctly,
  eventually found that it was one location dimension that was on attached to wrong wall
- made outer clamp thicker so it will deflect less, printing new test
- here's what spacing looks like clamp_spacing_1
- started working on geometry so that clamp will lock into place and not slip off, 
  trying one wall that it won't go past and one chamfered less deep wall that it can deflect through and then be locked into place
- printing test of this, tpu has been drying for about 10 hours, might try to print one of each for testing
- trying the original 'flexure design' and a flexure design with less legs and more spacing to hopefully allow more deflection and surface area touching; like this:
flexure_with_less

10/12/2024
---
- looked for where i saw yolo architecture which is here [https://www.datacamp.com/blog/yolo-object-detection-explained]()
- trying out roboflow
- created training dataset with roboflow off of 31 images of the robot arm, labelled photos with robot arm and monitor, roboflow allowed augementation of data set to get training data up to 48 images
- exported training file, now to try to train pretrained v8s with it
- found this and going to follow it for tutorial, [https://blog.roboflow.com/how-to-train-yolov8-on-a-custom-dataset/]()
- above tutorial was not for a python script i think
- found a video tutorial from ultralytics, https://www.youtube.com/watch?v=LNwODJXcvt4, going to try to train from terminal based on the code line they use
- used this to train,didn't take too long (.028 hours), used gpu, results saved to runs/detect/train4

    yolo task=detect mode=train model=yolov8s.pt data=data.yaml epochs=20 imgsz=640 device=0

- looks like it has good results for detecting robotic arm
- now going to validate (need to copy best.pt into programming because giving path was not working)

    yolo task=detect mode=val model=best.pt data=data.yaml device=0

- now going to test model with test images
- something was wrong in code i inputted and it just used two of the generic photos that yolo has
  which were zidane and bus. it didn't recognize any of them so i think this may have created a full new model off of the small data i had
- tried it on one of the test images and it did not work either, didn't show any boxes at all
- going to try a live detection test just in room to see if it is custom with pretrained or custom based off my dataset
- live test showed showed no boxes or object detection, pretty sure i just trained new model from scratch
- after reading some of the discussion on this [https://www.reddit.com/r/computervision/comments/16q1csv/is_it_possible_to_add_new_classes_to_pretrained/](https://www.reddit.com/r/computervision/comments/16q1csv/is_it_possible_to_add_new_classes_to_pretrained/)
  I think that if we want to add new classes, robotic-arm or whatever, we will need to still train on a full dataset containing coco and our new object data
- depending on our use case, we may be able to train new model on just our new data for very specific objects
- need to look into how long it would take to retrain on COCO and new data, probably need more photos of robotic-arm
- at lab, trained model would not recognize robot arm or monitor
- tried yolo v11s, works well
- going to try to get custom trained dataset to detect things before i try to use coco model with extra pretrained images
- took 130 photos of keyboards, robot arm, monitors, now going to label and make into dataset, prob need to train for more than 20 epochs
- labelled 133 photos with keyboard, robot arm, monitor, and mouse, created training set with augmentation for a total of 379 images
- trying to train in lab, can't access path variable without adminstrative position, trying virtual environment that pycharm gave option to, worked
- training on new dataset for 50 epochs, took .094 hours, results look stronger, now to try
- new trained dataset works well, might need to augment to flip photos around to give it a better chance at recognizing things upside down.
  I did notice that it doesn't work at all angles. Only tested on keyboard, monitor and mouse, robotic arm is far from camera when attached to pc
- still not exactly sure what this is doing, is it transfer learning but only having outputs for the classes that the custom dataset has or training from scratch
- for now i think this proves that we can train the model to detect specific objects using roboflow for labelling and with enough images

10/11/2024
---
- trying to get labelImg working
- python would not recognize it and couldnt figure out how to add it to path
- eventually found the .exe file in files and ran it from that but it would crash
  after a minute or so
- had weekly meeting - learned about roboflow

10/10/2024
---
- took 31 images of robot arm for transfer learning test
- watched some tutorials on how to train on custom data sets for YOLO
- did some research on how transfer learning freezing would work

Before 10/10/2024 (generally, at least what I can remember)
---
- got realsense camera working on python with pyrealsense2, cv_test.py
- checked depth readings, pretty accurate 
- got yolo v5 working with camera based on ultralytics github and chatgpt information, detection_test.py
- started setup.md for how to get stuff started

Random old stuff:

old way before table:

Comparison image 1
-using yolo11x.pt (biggest one, only going to do for image 1 cause not significantly different from 11s):

- using yolo11s.pt:

- using yolo11n.pt:

- using custom trained dataset on stuff in lab


Comparison image 2
- using yolo11s.pt:

- using yolo11n.pt:

- using custom trained dataset on stuff in lab


Comparison image 3
- using yolo11s.pt:

- using yolo11n.pt:

- using custom trained dataset on stuff in lab


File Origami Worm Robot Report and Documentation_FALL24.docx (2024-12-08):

Rigiccordian-based Origami Worm Robot

Fall 2024

ME-400

Andrew Carr

Dr. Mohammad Hasan

Introduction

As part of ME-400, I worked on redesigning the worm robot for better movement. The previous robot was designed quickly as a proof of concept. It was tedious to assemble and change components, the motors were difficult to control, and things would often break. So, before we focused on movement, the robot was redesigned to fix each of these problems. After this, the focus was realigned on optimizing movement. The friction pads were notoriously inconsistent where sometimes they would work like we expected, sometimes do nothing and sometimes do the opposite of what we expected. Work was focused on trying different sawtooth friction pad designs.

A Bambu P1S was used for all 3D printing.

This report will highlight changes and provide documentation for assembly of hardware and an outline for software design.

The work done on the robot started about halfway through the quarter, the other half was spent on computer vision.

Robot Redesign

Clamp Spring System:

Previously, the origami spring was attached with tape to the supports. During testing, the spring would slip and was difficult to detach and reattach. A new mechanism was designed to allow quick on/off and one that would hold the spring in place well.

The new system was a clamp that would sandwich the spring between two plastic pieces. The clamp has edges that when fully put together will add extra resistance to coming apart.

paper_fit_test

Figure 1. Original test clamp for proof of concept

clamp_spacing_1

Figure 2. Clamp mating cross-section

Friction pad fast-mounting system:

Since the new spring attachment system had an outer shell, this opened up the opportunity to add a way to attach friction pads directly. On the old system, friction pads were taped on. The new system used rails on the friction pads that would slide into a slot on the outer shell of the clamp. The rails are 1.3 mm thick, and the slot is 1.5 mm thick.

new_frictpad

Figure 3. Friction pad with rails

assembled_1

Figure 4. Clamp system with fast-mountain friction pad system

Servos to DC Motors:

The original design used continous rotation servos for actuation. These were quick to implement, cheap and in the lab. The servos were small and weak so they sometimes could not compress the asymetrical spring at the same rate. Also, they had a small plastic shaft with a star design. This made it very difficult to 3D print new parts that would couple securely.

The right DC motor could solve all the problems with the servos. We needed a DC motor with an encoder that was strong enough to compress the robot completely. A quick calculation was done to estimate a max torque necessary to hold the robot in full compression and to compress the robot at a rate similar to the previous robot (see Appendix A). Stiffness data was used from the previous paper.

A Pololu micro-geared DC motor was selected. An option with a 298:1 gear ration fulfilled both the torque and speed. This motor was also very small and had an encoder built in.


Figure 5. Pololu Micro Metal Gearmotor (pololu.com/product/5147)

A Pololu dual motor driver was used to drive the two motors off of one chip.


Figure 6. Pololu DRV8833 Dual Motor Driver (pololu.com/product/2130)

Since new motors were used, the motor mounts needed to be redesigned. The mounts were designed to be in line with the other sides connection, and were to be as minimal as possible. Also, the mount features a spot for a scew to be screwed in to hold the other side of the tether. There were many different spots for where the tether could be attached.

dc_motor_mounted

Figure 7. First Iteration Motor Mount Design

Pulleys:

Pulleys were designed to fit on the motor shafts and needed to be able to attach the tether well. The pulleys press fit tightly onto the shaft. There is a hole for a screw to lock onto the shaft but the plastic threads do not hold well enough to do anything. The pulley has a hole to tie the tether into.

DC_pulley

Figure 8. Pulley

Fully Assembled:

With all of these changes, the problems with the old robot were fixed. This robot was strong, and it was easy to test new friction pads and worm angles.

close_up_robot

Figure 9. Redesigned Robot fully assembled

Robot Control

User Input:

Previously, the robot was controlled by a timed sequence. This was easy to implement but without any speed control, the motors would get out of sink and it was hard to reallign them. A way to control the robot live would make the testing and movement much easier.

An analog joystick was used for user input. A plastic joystick was fit to the small metal joystick piece, and a housing was made to hold the joystick and Arduino side by side.

joystick_module

Figure 10. Analog Joystick


Figure 11. Joystick and Arduino Setup

Pushing the joystick forward compresses both motors and vice versa. Pushing it to one side rotates a given motor depending on if its forwards or backwards.

xy_decode

Figure 12: Joystick Decoder

Controller:

A speed-based PI controller was used to go to a specifc speed based on how forward the joystick was. If the motors become off, the system corrects this until the motors angles are realligned.

vel_control_flow

Figure 13. PI speed controller based on joystick inputs

Assembly/Wiring

Worm assembly:

Appendix:

[A] Motor Torque and Speed Calculation

motor_torque_calc

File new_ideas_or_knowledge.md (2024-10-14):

Might not use this (10/13/2024)

Regarding the camera:
---

- Realsense2 provides RGBD data
  - Distance is achieved using 2 cameras and triangularization (stereo vision). 
  It is equipped with infrared emitters which enables higher quality using IR dot patterns.
  - IR is not necessary for use but gives much more quality. 
  Outdoors or where there might be a high amount of IR, the dot patterns might not be seen or used.

Regarding Computer Vision:
---
- YOLO (You Only Look Once)
  - algorithm used for object detection
  - When using RGBD data, we need to add another input to the neural network
  - Works very generally by gridding image, bounding boxes, getting rid of boxes with not enough object, and non-max suppression(?).
- deeplab for wall, floor, etc detection
- labelImg for labeling images and exporting in YOLO format

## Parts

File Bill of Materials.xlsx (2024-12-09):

# | ITEM | Quantity | Price | Link | Total Price | Comments | Cost of materials
1 | Pololu 298:1 Micro Metal Gearmotor MP 6V with 12 CPR Encoder, Side Connector | 2 | $25.95 | www.pololu.com/product/5147 | $51.90 |  | $179.06
2 | Pololu DRV8833 Dual Motor Driver Carrier | 1 | $9.95 | www.pololu.com/product/2130 | $9.95 |  | without tax/shipping
3 | Arduino Uno R3 | 1 | $29.00 | www.amazon.com/Arduino-A000066-ARDUINO-UNO-R3 | $29.00 | can use offbrand one and will be cheaper
4 | Analog Joystick | 1 | $9.99 | www.amazon.com/Joystick-Controller | $9.99 | will have different base joystick so will need to change printed joystick to fit
5 | 6 Pin JST SH 1.0mm Cable Connector | 1 | $9.49 | www.amazon.com/dp/B0BKSNMC (https://www.amazon.com/dp/B0BKSNMCV4?ref=ppx_yo2ov_dt_b_fed_asin_title) | $9.49
6 | M1.6 x 3mm Round Flat Head Machine Screws | 1 | $5.99 | www.amazon.com/dp/B0CTMKH2CX (https://www.amazon.com/dp/B0CTMKH2CX?ref=ppx_yo2ov_dt_b_fed_asin_title&th=1) | $5.99
7 | PLA Filament | 1 | $13.99 | www.amazon.com/ELEGOO-Filament-Dimensional | $13.99
8 | Breadboard Power Supply Module | 1 | $6.99 | www.amazon.com/DIYables-Breadboard-Supply | $6.99
9 | Breadboard | 1 | $8.79 | www.amazon.com/Breadboards (https://www.amazon.com/Breadboards-Solderless-Breadboard-Distribution-Connecting/dp/B07DL13RZH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) | $8.79
10 | Multicolored Dupont Wire 120 pcs | 1 | $6.98 | www.amazon.com/Multicolored (https://www.amazon.com/Elegoo-EL-CP-004-Multicolored-Breadboard-arduino/dp/B01EV70C78) | $6.98
11 | Machine Screw Assortment Kit, M2 M3 M4 M5 | 1 | $25.99 | www.amazon.com/Machine-Assortment-Metric- | $25.99
12
13
14
15
16
17
18
19
20
21

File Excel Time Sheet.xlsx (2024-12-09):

Date | Time In | Time out | Delta Time | Number of minutes | Number of hours | Money | Logged? | Total Hours | Total Money | Taxed | Week | Hour Totals | Money
2024-09-28 | 15:00:00 | 17:00:00 | 2:00:00 | 120.00 | 2.00 | $45.00 | y | 91.87 | $2067.00 | $1694.94 | 1 | 2:00:00 | $45.00
2024-09-30 | 13:00:00 | 14:30:00 | 1:30:00 | 90.00 | 1.50 | $33.75 | y |  |  |  | 2 | 9:45:00 | $219.38
2024-09-30 | 15:30:00 | 17:55:00 | 2:25:00 | 145.00 | 2.42 | $54.37 | y |  |  |  | 3 | 12:08:00 | $273.00
2024-09-30 | 23:00:00 | 0:00:00 | 1:00:00 | 60.00 | 1.00 | $22.50 | y |  |  |  | 4 | 9:49:00 | $220.88
2024-10-01 | 11:00:00 | 11:55:00 | 0:55:00 | 55.00 | 0.92 | $20.63 | y |  |  |  | 5 | 11:24:00 | $256.50
2024-10-02 | 13:20:00 | 14:40:00 | 1:20:00 | 80.00 | 1.33 | $30.00 | y |  |  |  | 6 | 8:41:00 | $195.37
2024-10-05 | 12:20:00 | 13:55:00 | 1:35:00 | 95.00 | 1.58 | $35.63 | y |  |  |  | 7 | 10:25:00 | $234.38
2024-10-06 | 13:55:00 | 14:55:00 | 1:00:00 | 60.00 | 1.00 | $22.50 | y |  |  |  | 8 | 14:49:00 | $333.38
2024-10-10 | 18:30:00 | 18:58:00 | 0:28:00 | 28.00 | 0.47 | $10.50 | y |  |  |  | 9 | 5:24:00 | $121.50
2024-10-10 | 20:00:00 | 21:00:00 | 1:00:00 | 60.00 | 1.00 | $22.50 | y |  |  |  | 10 | 4.77 | $78.38
2024-10-11 | 11:53:00 | 12:30:00 | 0:37:00 | 37.00 | 0.62 | $13.88 | y |  |  |  | 11
2024-10-12 | 11:39:00 | 13:43:00 | 2:04:00 | 124.00 | 2.07 | $46.50 | y
2024-10-12 | 15:03:00 | 17:36:00 | 2:33:00 | 153.00 | 2.55 | $57.37 | y
2024-10-13 | 10:08:00 | 13:05:00 | 2:57:00 | 177.00 | 2.95 | $66.37 | y
2024-10-13 | 14:04:00 | 14:54:00 | 0:50:00 | 50.00 | 0.83 | $18.75 | y
2024-10-13 | 21:56:00 | 23:35:00 | 1:39:00 | 99.00 | 1.65 | $37.12 | y
2024-10-14 | 19:35:00 | 21:35:00 | 2:00:00 | 120.00 | 2.00 | $45.00 | y
2024-10-15 | 23:37:00 | 0:30:00 | 0:53:00 | 53.00 | 0.88 | $19.87 | y
2024-10-18 | 22:05:00 | 23:39:00 | 1:34:00 | 94.00 | 1.57 | $35.25 | y
2024-10-19 | 16:09:00 | 18:25:00 | 2:16:00 | 136.00 | 2.27 | $51.00 | y
2024-10-20 | 20:02:00 | 23:08:00 | 3:06:00 | 186.00 | 3.10 | $69.75 | y
2024-10-21 | 19:53:00 | 21:16:00 | 1:23:00 | 83.00 | 1.38 | $31.12 | y
2024-10-23 | 13:57:00 | 15:08:00 | 1:11:00 | 71.00 | 1.18 | $26.62 | y
2024-10-23 | 20:22:00 | 21:51:00 | 1:29:00 | 89.00 | 1.48 | $33.38 | y
2024-10-27 | 11:44:00 | 16:49:00 | 5:05:00 | 305.00 | 5.08 | $114.37 | y
2024-10-27 | 17:46:00 | 18:12:00 | 0:26:00 | 26.00 | 0.43 | $9.75 | y
2024-10-27 | 22:01:00 | 23:51:00 | 1:50:00 | 110.00 | 1.83 | $41.25 | y
2024-11-02 | 11:15:00 | 13:00:00 | 1:45:00 | 105.00 | 1.75 | $39.37 | y
2024-11-02 | 14:06:00 | 14:50:00 | 0:44:00 | 44.00 | 0.73 | $16.50 | y
2024-11-03 | 10:01:00 | 14:15:00 | 4:14:00 | 254.00 | 4.23 | $95.25 | y
2024-11-03 | 19:35:00 | 20:57:00 | 1:22:00 | 82.00 | 1.37 | $30.75 | y
2024-11-03 | 22:40:00 | 23:16:00 | 0:36:00 | 36.00 | 0.60 | $13.50 | y
2024-11-05 | 21:30:00 | 22:40:00 | 1:10:00 | 70.00 | 1.17 | $26.25 | y
2024-11-06 | 19:40:00 | 21:45:00 | 2:05:00 | 125.00 | 2.08 | $46.88 | y
2024-11-06 | 22:44:00 | 23:32:00 | 0:48:00 | 48.00 | 0.80 | $18.00 | y
2024-11-07 | 18:10:00 | 19:10:00 | 1:00:00 | 60.00 | 1.00 | $22.50 | y
2024-11-07 | 21:35:00 | 22:15:00 | 0:40:00 | 40.00 | 0.67 | $15.00 | y
2024-11-08 | 13:05:00 | 13:42:00 | 0:37:00 | 37.00 | 0.62 | $13.88 | y
2024-11-08 | 18:38:00 | 20:35:00 | 1:57:00 | 117.00 | 1.95 | $43.87 | y
2024-11-10 | 20:10:00 | 22:18:00 | 2:08:00 | 128.00 | 2.13 | $48.00 | y
2024-11-11 | 10:58:00 | 14:41:00 | 3:43:00 | 223.00 | 3.72 | $83.63 | y
2024-11-11 | 15:07:00 | 18:22:00 | 3:15:00 | 195.00 | 3.25 | $73.12 | y
2024-11-12 | 20:28:00 | 21:55:00 | 1:27:00 | 87.00 | 1.45 | $32.63 | y
2024-11-14 | 21:55:00 | 23:50:00 | 1:55:00 | 115.00 | 1.92 | $43.13 | y
2024-11-15 | 12:10:00 | 15:20:00 | 3:10:00 | 190.00 | 3.17 | $71.25 | y
2024-11-17 | 17:25:00 | 18:44:00 | 1:19:00 | 79.00 | 1.32 | $29.63 | y
2024-11-18 | 12:09:00 | 13:18:00 | 1:09:00 | 69.00 | 1.15 | $25.88 | y
2024-11-20 | 19:55:00 | 22:21:00 | 2:26:00 | 146.00 | 2.43 | $54.75 | y
2024-11-22 | 15:30:00 | 16:30:00 | 1:00:00 | 60.00 | 1.00 | $22.50 | y
2024-11-28 | 16:05:00 | 16:54:00 | 0:49:00 | 49.00 | 0.82 | $18.38 | y
2024-12-03 | 20:29:00 | 21:00:00 | 0:31:00 | 31.00 | 0.52 | $11.63
2024-12-06 | 22:29:00 | 23:59:00 | 1:30:00 | 90.00 | 1.50 | $33.75
2024-12-07 | 19:11:00 | 20:39:00 | 1:28:00 | 88.00 | 1.47 | $33.00
2024-12-08 | 12:53:00 | 14:10:00 | 1:17:00 | 77.00 | 1.28 | $28.88
2024-12-08 | 18:34:00 | 21:15:00 | 2:41:00 | 161.00 | 2.68 | $60.37
 | DON'T FORGET TO SAVE (local)

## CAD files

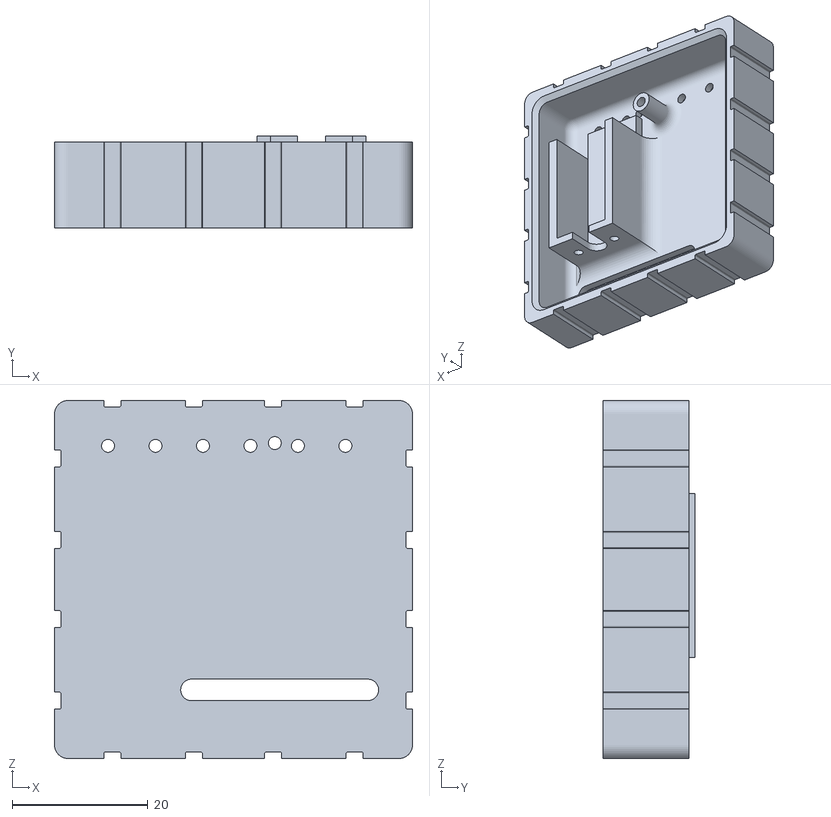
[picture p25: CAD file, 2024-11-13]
CAD/STLs/DC Motor/DC Motor Mount.STL
52.8 x 13.6 x 52.8

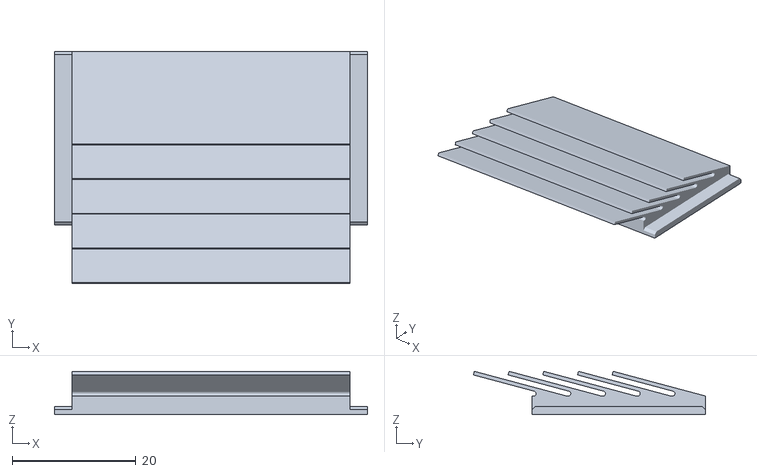
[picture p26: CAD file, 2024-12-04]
CAD/STLs/Friction Pads/Friction_straightangled_long_15_4^Worm_Robot.STL
50.5 x 37.5 x 7.00

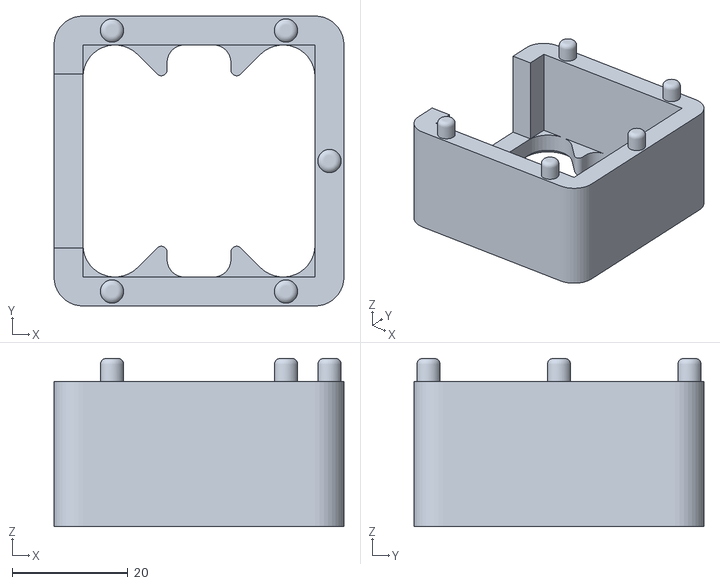
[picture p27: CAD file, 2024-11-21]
CAD/STLs/Gear box^Worm_Robot.STL
50.0 x 50.0 x 29.0

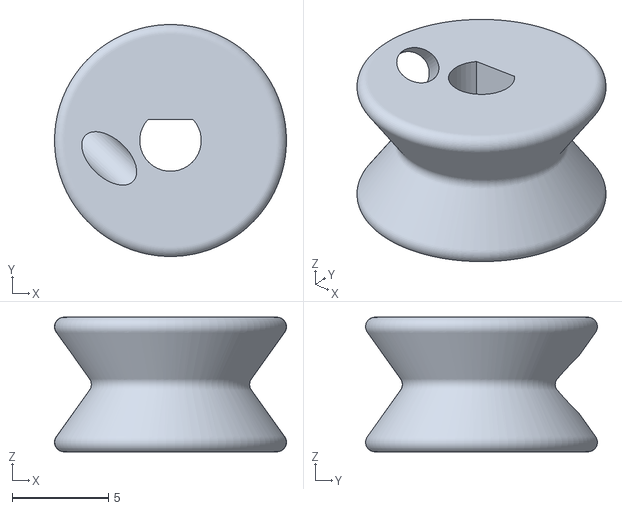
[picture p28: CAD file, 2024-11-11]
CAD/STLs/DC Motor/DC Pulley.STL
12.1 x 12.0 x 7.00

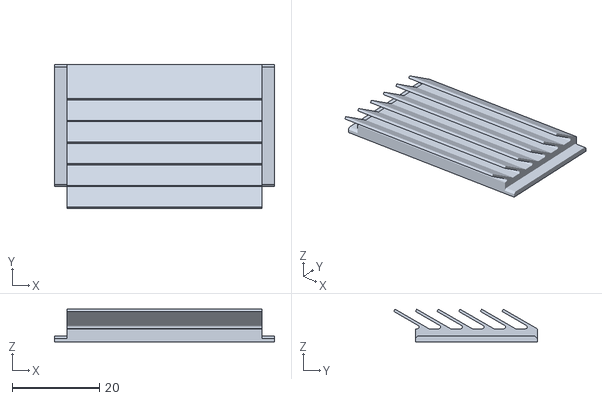
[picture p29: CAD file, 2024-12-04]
CAD/STLs/Friction Pads/Friction_straightangled_long_30_4.5^Worm_Robot.STL
50.5 x 32.9 x 7.50

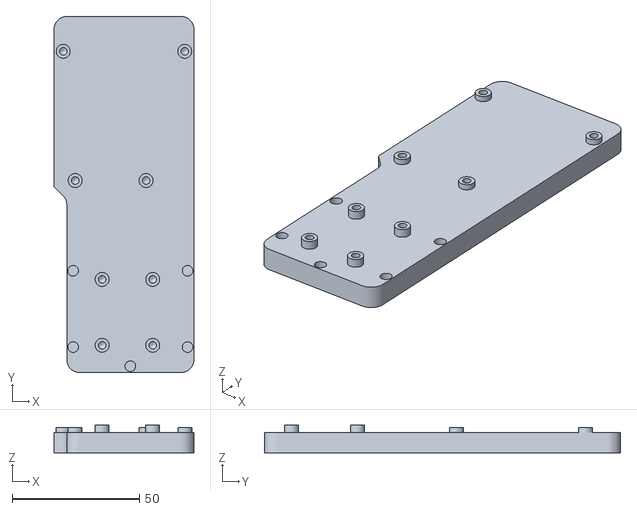
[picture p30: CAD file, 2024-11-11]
CAD/STLs/Joystick Base^Worm_Robot.STL
55.0 x 140.0 x 11.0

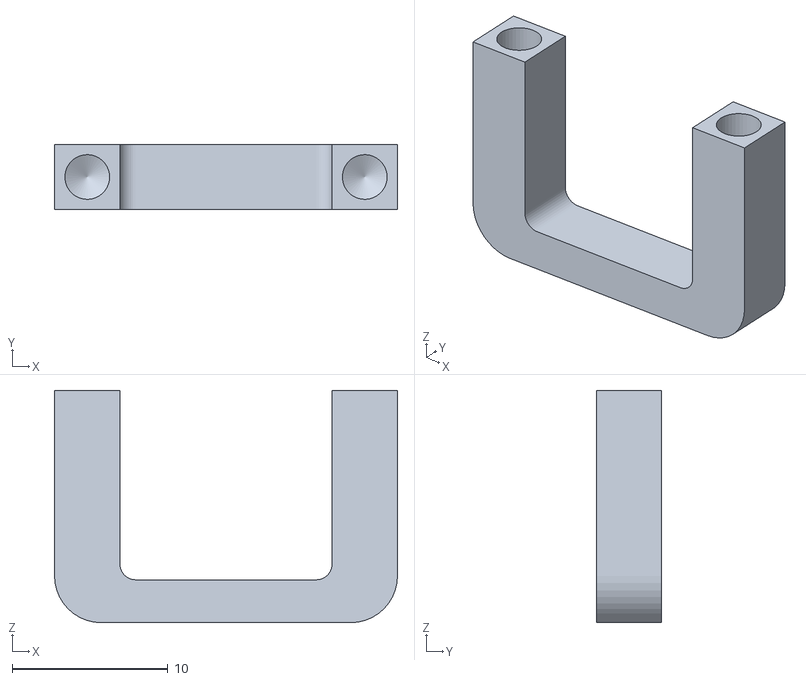
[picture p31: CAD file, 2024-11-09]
CAD/STLs/DC Motor/DC Clamp^Worm_Robot.STL
22.0 x 4.20 x 14.9

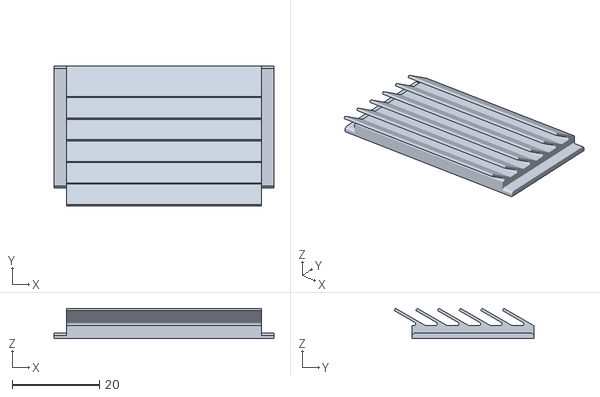
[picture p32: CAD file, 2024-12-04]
CAD/STLs/Friction Pads/Friction_straightangled_long_30_5^Worm_Robot.STL
50.5 x 32.1 x 7.00

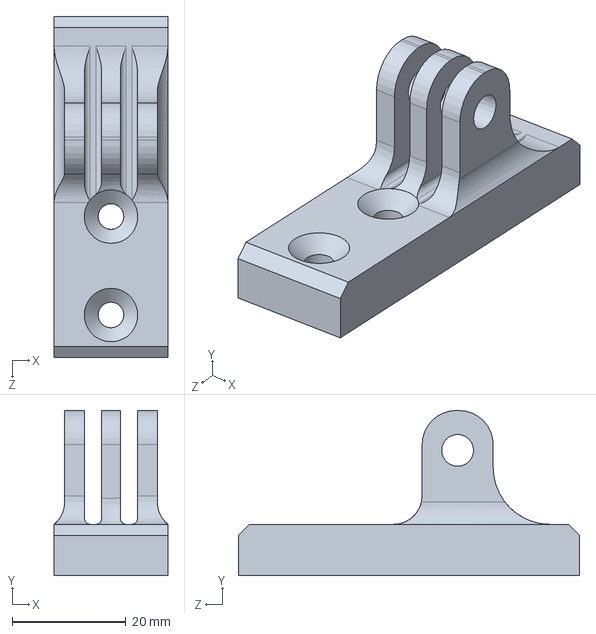
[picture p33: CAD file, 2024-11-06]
CAD/STLs/Matty Light Mount.SLDPRT
20.0 x 29.0 x 60.0 mm

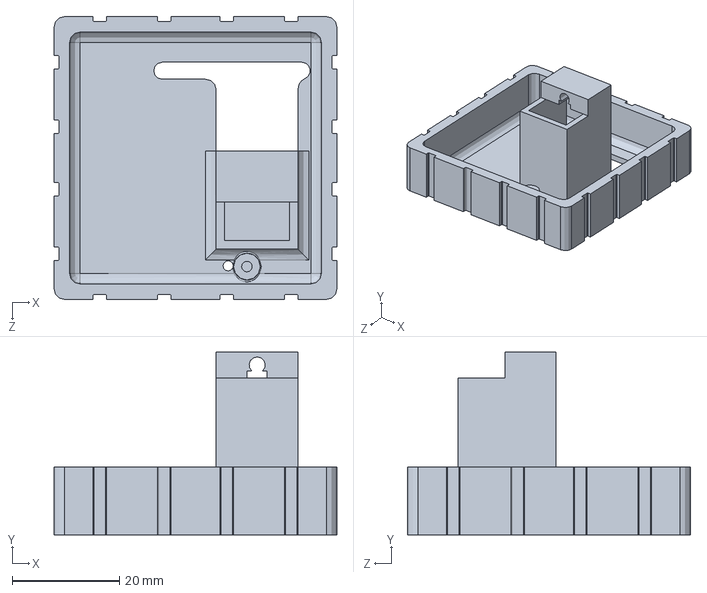
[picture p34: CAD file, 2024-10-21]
CAD/SolidWorks/Servo Motor Mounts.sldprt
52.8 x 34.1 x 52.8 mm

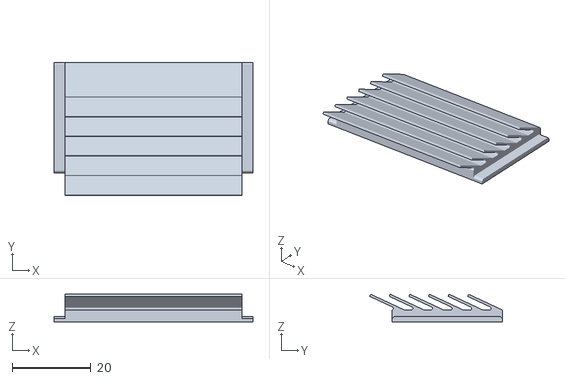
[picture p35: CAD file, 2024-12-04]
CAD/STLs/Friction Pads/Friction_straightangled_long_25_4.5^Worm_Robot.STL
50.5 x 33.7 x 7.00

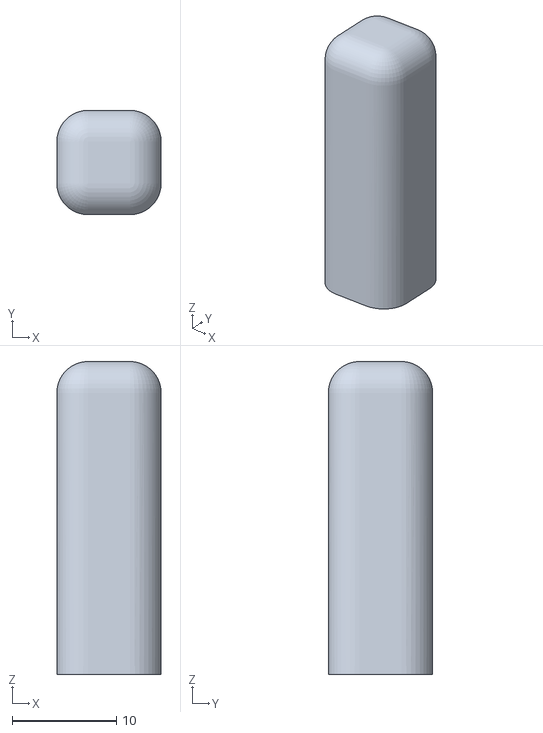
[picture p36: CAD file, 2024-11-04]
CAD/STLs/Joystick Top^Worm_Robot.STL
10.0 x 10.0 x 30.0

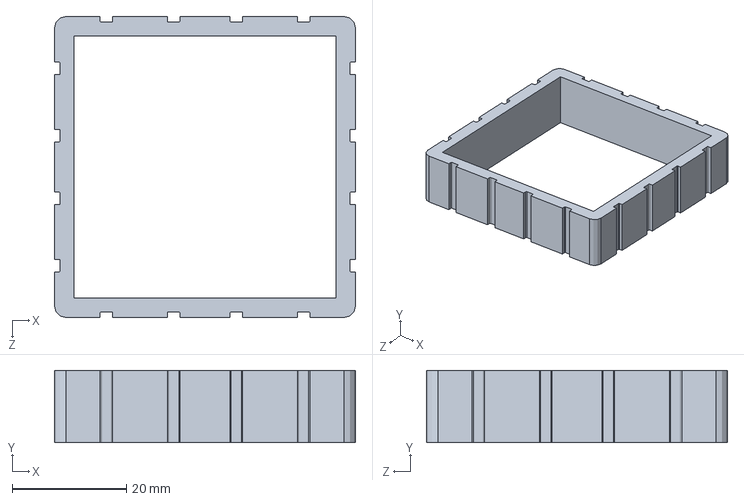
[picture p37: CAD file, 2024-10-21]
CAD/SolidWorks/Servo Mount Clamp Test.SLDPRT
52.8 x 12.7 x 52.8 mm

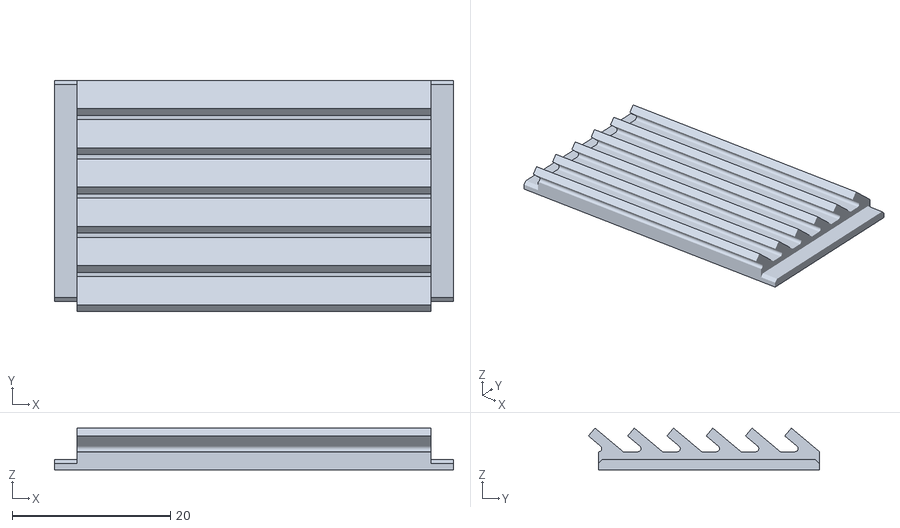
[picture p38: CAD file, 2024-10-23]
CAD/STLs/Elevated Friction_1^Worm_Robot.STL
50.5 x 29.3 x 5.30

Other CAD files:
CAD/SolidWorks/Worm_Robot.SLDASM
CAD/SolidWorks/DC Motor Mount.SLDPRT
CAD/SolidWorks/DC Pulley.SLDPRT
CAD/STLs/Friction Pads/Friction_straightangled_thinner^Worm_Robot.STL
CAD/STLs/Directional Friction Flexure_less.STL
CAD/STLs/Directional Friction Flexure_og.STL
CAD/STLs/Directional Friction Flexure_og_thick.STL
CAD/STLs/Friction Pads/Friction_straightangled_supersliced^Worm_Robot.STL
CAD/STLs/Friction Pads/Friction_straightangled_thinnest^Worm_Robot.STL
CAD/STLs/Mount Clamp Left^Worm_Robot.STL
CAD/STLs/Mount Clamp Right^Worm_Robot.STL
CAD/STLs/Mount Clamp^Worm_Robot.STL
CAD/STLs/Mount Clamp^Worm_Robot_walled.STL
CAD/STLs/Pulley Horn^Worm_Robot.STL
CAD/STLs/Pulley Horn^Worm_Robot_4.6.STL
CAD/STLs/Pulley Horn^Worm_Robot_4.7.STL
CAD/STLs/Servo Motor Mount.STL
CAD/STLs/Servo Motor Mounts.STL
CAD/STLs/Servo Mount Clamp Test.STL
CAD/SolidWorks/Directional Friction Flexure.sldprt
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

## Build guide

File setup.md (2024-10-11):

SETUP
---
---
This has all the info for setting up various CV models, cameras and any other necessary devices or software. 
Some code has different commands than the OS that might be being used.
Need a dedicated GPU for most tasks, so most command line code is from a windows device

---
INTEL REALSENSE DEPTH D435 SETUP
----
----
WINDOWS:
---
1. Download the SDK which is official for Windows
   [https://github.com/IntelRealSense/librealsense/releases/download/v2.56.1/Intel.RealSense.SDK-WIN10-2.56.1.7154-beta.exe]()
2. Run the installer
3. After connecting the camera to the computer, the camera should show up on the Intel RealSense Viewer

note: this step is not necessary to use REALSENSE with python script

Python:
---
1. As of 09/30/2024, pyrealsense2 is not supported with python 3.12. 
Need to be working with 3.11 or less. 
To use an older python version, use "pyenv" on mac and linux and "pyenv-win" on windows.
I am currently using Python 3.11.9.
2. Once you have working version of python "installed",
install pyrealsense2 with:

    pip install pyrealsense2

MATLAB:
---
There is a way to setup matlab with its own wrapper for the data from the RealSense,
but this requires some more research into adding matlab wrappers to path

For now, there is a way to use a python script to do all the interaction with the camera,
and send the data to MATLAB through a socket. This method works but may have some speed drawbacks.
In the future, a matlab script that can access the wrapper individually would be ideal. 

---
GPU
---
---
A GPU is necessary to run advanced Neural Network CV models.
A GPU can complete many matrix calculations in parallel which allows it to process ML models quickly and efficiently.

---
YOLO
---
---
1. Clone repository for desired YOLO model. For example (YOLOv5):

    git clone https://github.com/ultralytics/yolov5.git
2. To install all requirements with:

    "pip install -r requirements.txt"
3. Ensure correct version of "torch" and "torchvision" are installed to work with Nvidia CUDA using:

    import torch
    import torchvision
    print(torch.__version__)  # Check PyTorch version
    print(torchvision.__version__)  # Check Torchvision version
This should output something of the form " x.x.x+cu118 "

If it outputs "x.x.x+cpu" then uninstall torch and torchvision, and reinstall with:

    pip uninstall torch torchvision torchaudio
    pip install torch torchvision torchaudio --index-url https://download.pytorch.org/whl/cu118
*torchaudio may or may not be necessary
4. Ensure script is using the GPU with following:

    import torch
    import torchvision

    # Check if CUDA is available
    print(torch.cuda.is_available())

which should output True 
5. At this point, YOLO should be installed and ready for use from python script.

Transfer Learning with YOLO
---

Transfer learning allows a pretrained model to train and learn new classes and objects based on a custom dataset.
To do this, we need a custom dataset that is labelled and in the correct format for YOLO

To label (using labelImg):
1. Download labelImg with:

    pip install labelImg
2.

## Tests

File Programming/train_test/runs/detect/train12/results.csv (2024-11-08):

epoch | time | train/box_loss | train/cls_loss | train/dfl_loss | metrics/precision(B) | metrics/recall(B) | metrics/mAP50(B) | metrics/mAP50-95(B) | val/box_loss | val/cls_loss | val/dfl_loss | lr/pg0 | lr/pg1 | lr/pg2
1 | 354.364 | 1.31122 | 2.62917 | 1.38021 | 0.56705 | 0.42134 | 0.43986 | 0.30065 | 1.20395 | 1.5791 | 1.26105 | 0.00333072 | 0.00333072 | 0.00333072
2 | 701.906 | 1.35537 | 2.11741 | 1.4073 | 0.46504 | 0.31539 | 0.30753 | 0.19983 | 1.41341 | 2.00364 | 1.42464 | 0.0065321 | 0.0065321 | 0.0065321
3 | 1046.49 | 1.50471 | 2.46305 | 1.52486 | 0.34349 | 0.19452 | 0.1616 | 0.09411 | 1.63818 | 2.54507 | 1.6381 | 0.00960149 | 0.00960149 | 0.00960149
4 | 1390.02 | 1.5982 | 2.69529 | 1.60853 | 0.39322 | 0.21729 | 0.18673 | 0.11097 | 1.58274 | 2.40911 | 1.59615 | 0.009406 | 0.009406 | 0.009406
5 | 1734.27 | 1.53861 | 2.53656 | 1.57287 | 0.36989 | 0.24156 | 0.21066 | 0.12905 | 1.52456 | 2.26774 | 1.57038 | 0.009208 | 0.009208 | 0.009208
6 | 2076.84 | 1.49919 | 2.39606 | 1.53909 | 0.39569 | 0.27378 | 0.24875 | 0.16134 | 1.49168 | 2.13881 | 1.51723 | 0.00901 | 0.00901 | 0.00901
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

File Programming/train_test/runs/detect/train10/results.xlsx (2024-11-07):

epoch | train/box_loss | train/cls_loss | train/dfl_loss | metrics/precision(B) | metrics/recall(B) | metrics/mAP50(B) | metrics/mAP50-95(B) | val/box_loss | val/cls_loss | val/dfl_loss | lr/pg0 | lr/pg1 | lr/pg2
1 | 1.3056 | 3.1963 | 1.37 | 0.62398 | 0.46698 | 0.48196 | 0.34207 | 1.1187 | 1.6534 | 1.1798 | 3.9302e-05 | 3.9302e-05 | 3.9302e-05
2 | 1.2816 | 1.9596 | 1.3496 | 0.63835 | 0.47583 | 0.50079 | 0.35049 | 1.1563 | 1.502 | 1.2152 | 7.0851e-05 | 7.0851e-05 | 7.0851e-05
3 | 1.2796 | 1.7529 | 1.3498 | 0.58772 | 0.47136 | 0.48799 | 0.34304 | 1.1725 | 1.5125 | 1.2384 | 9.4611e-05 | 9.4611e-05 | 9.4611e-05
4 | 1.257 | 1.6247 | 1.3329 | 0.61623 | 0.46892 | 0.50032 | 0.34854 | 1.1679 | 1.446 | 1.2334 | 8.2954e-05 | 8.2954e-05 | 8.2954e-05
5 | 1.2186 | 1.493 | 1.3046 | 0.63288 | 0.48123 | 0.5183 | 0.36405 | 1.1588 | 1.3874 | 1.2281 | 7.1272e-05 | 7.1272e-05 | 7.1272e-05
6 | 1.1886 | 1.3848 | 1.2815 | 0.64337 | 0.48408 | 0.52697 | 0.37262 | 1.148 | 1.3622 | 1.2215 | 5.959e-05 | 5.959e-05 | 5.959e-05
7 | 1.1599 | 1.2988 | 1.2596 | 0.63059 | 0.50482 | 0.53464 | 0.37811 | 1.1419 | 1.3298 | 1.2175 | 4.7908e-05 | 4.7908e-05 | 4.7908e-05
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

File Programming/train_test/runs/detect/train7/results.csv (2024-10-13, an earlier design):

epoch | time | train/box_loss | train/cls_loss | train/dfl_loss | metrics/precision(B) | metrics/recall(B) | metrics/mAP50(B) | metrics/mAP50-95(B) | val/box_loss | val/cls_loss | val/dfl_loss | lr/pg0 | lr/pg1 | lr/pg2
1 | 7.06992 | 1.36095 | 3.09542 | 1.41823 | 0.02471 | 0.64052 | 0.28798 | 0.20473 | 1.12823 | 3.22931 | 1.06784 | 0.0003 | 0.0003 | 0.0003
2 | 13.3016 | 1.23295 | 1.72411 | 1.30944 | 0.01945 | 0.64624 | 0.50283 | 0.33424 | 1.06147 | 3.05847 | 1.06135 | 0.000600373 | 0.000600373 | 0.000600373
3 | 19.4324 | 1.14974 | 1.31054 | 1.25788 | 0.02507 | 0.65632 | 0.49139 | 0.30918 | 1.0955 | 3.08121 | 1.10336 | 0.00088837 | 0.00088837 | 0.00088837
4 | 25.5453 | 1.13282 | 1.21776 | 1.24083 | 0.91326 | 0.1807 | 0.61351 | 0.40612 | 1.15898 | 2.51552 | 1.11812 | 0.00116399 | 0.00116399 | 0.00116399
5 | 31.706 | 1.15049 | 1.20343 | 1.2506 | 0.78155 | 0.56806 | 0.80387 | 0.48486 | 1.27531 | 1.87614 | 1.25182 | 0.001151 | 0.001151 | 0.001151
6 | 37.8648 | 1.11301 | 1.13928 | 1.24506 | 0.80853 | 0.71158 | 0.84309 | 0.5066 | 1.29955 | 1.56164 | 1.28079 | 0.00112625 | 0.00112625 | 0.00112625
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

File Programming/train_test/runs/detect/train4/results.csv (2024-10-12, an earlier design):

epoch | train/box_loss | train/cls_loss | train/dfl_loss | metrics/precision(B) | metrics/recall(B) | metrics/mAP50(B) | metrics/mAP50-95(B) | val/box_loss | val/cls_loss | val/dfl_loss | lr/pg0 | lr/pg1 | lr/pg2
1 | 1.7652 | 3.2984 | 1.7287 | 0.00605 | 0.6746 | 0.0227 | 0.00846 | 1.2715 | 3.4095 | 1.3627 | 3.334e-05 | 3.334e-05 | 3.334e-05
2 | 1.3932 | 3.1125 | 1.5334 | 0.00671 | 0.7619 | 0.06641 | 0.03384 | 1.1396 | 3.27 | 1.2437 | 7.9224e-05 | 7.9224e-05 | 7.9224e-05
3 | 1.2592 | 2.9512 | 1.3949 | 0.00776 | 0.87302 | 0.52139 | 0.28719 | 0.99224 | 3.1672 | 1.1484 | 0.00012016 | 0.00012016 | 0.00012016
4 | 1.3087 | 2.7503 | 1.4367 | 0.00778 | 0.87302 | 0.59207 | 0.42311 | 0.95183 | 3.1887 | 1.1585 | 0.00015614 | 0.00015614 | 0.00015614
5 | 1.1721 | 2.4698 | 1.2701 | 0.00779 | 0.87302 | 0.57691 | 0.41702 | 0.92654 | 3.1812 | 1.1571 | 0.00018717 | 0.00018717 | 0.00018717
6 | 1.1638 | 2.0786 | 1.3026 | 0.00778 | 0.87302 | 0.58794 | 0.4183 | 0.91696 | 3.1395 | 1.0842 | 0.00021325 | 0.00021325 | 0.00021325
7 | 1.0165 | 1.9701 | 1.2447 | 0.00776 | 0.87302 | 0.65946 | 0.50441 | 0.89675 | 3.1031 | 1.0814 | 0.00023438 | 0.00023438 | 0.00023438
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

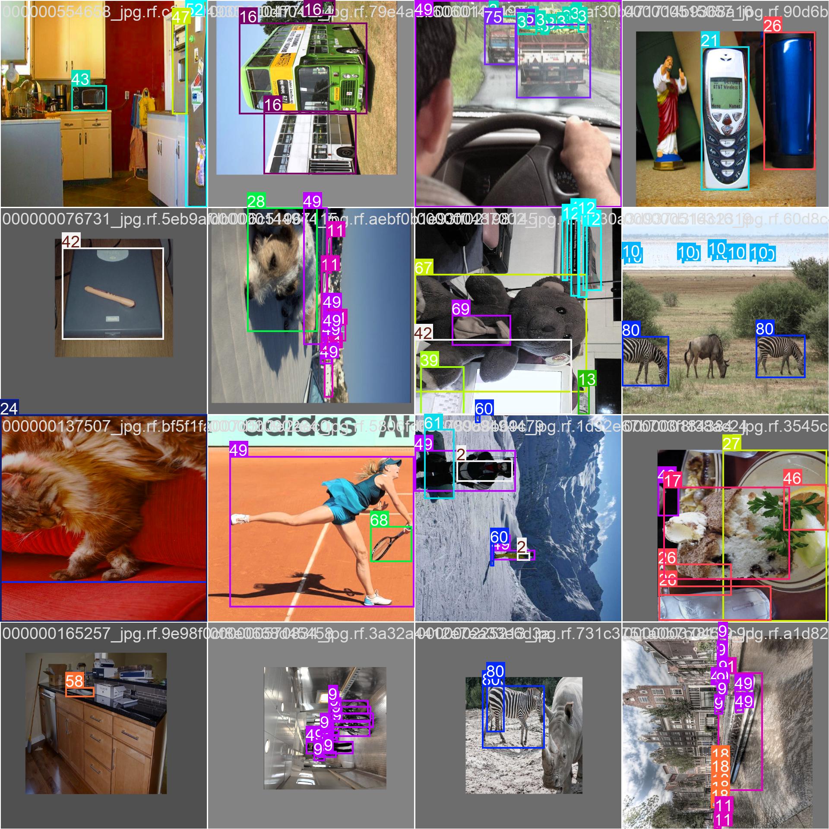
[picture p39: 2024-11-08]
Programming/train_test/runs/detect/train12/train_batch50960.jpg

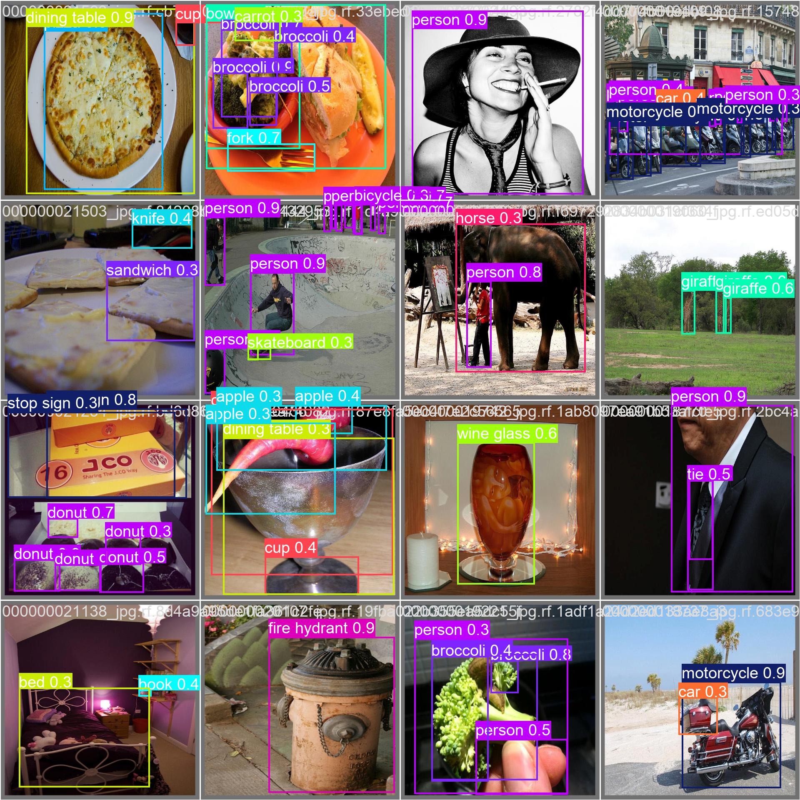
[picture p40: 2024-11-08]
Programming/train_test/runs/detect/train12/val_batch2_pred.jpg

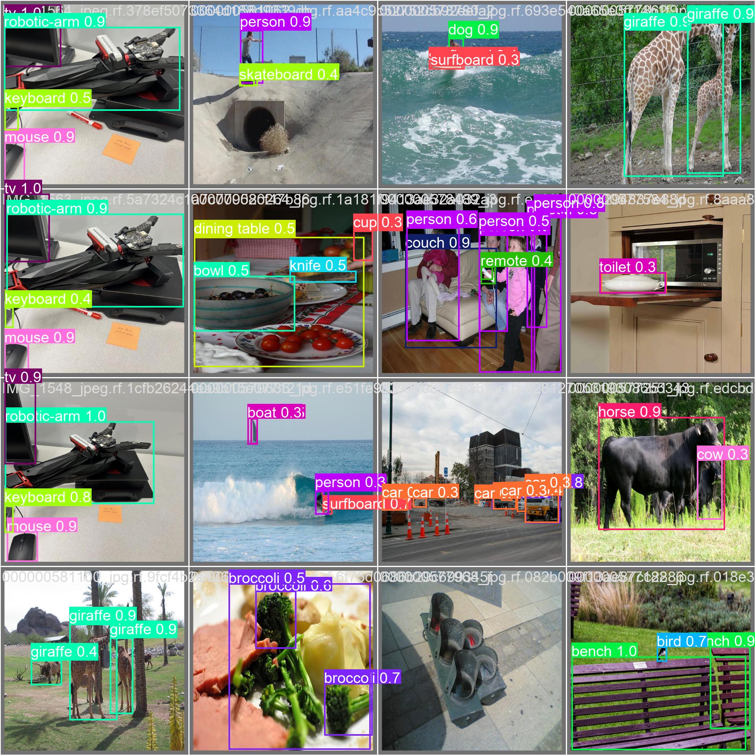
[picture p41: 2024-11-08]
Programming/train_test/runs/detect/train12/val_batch0_pred.jpg

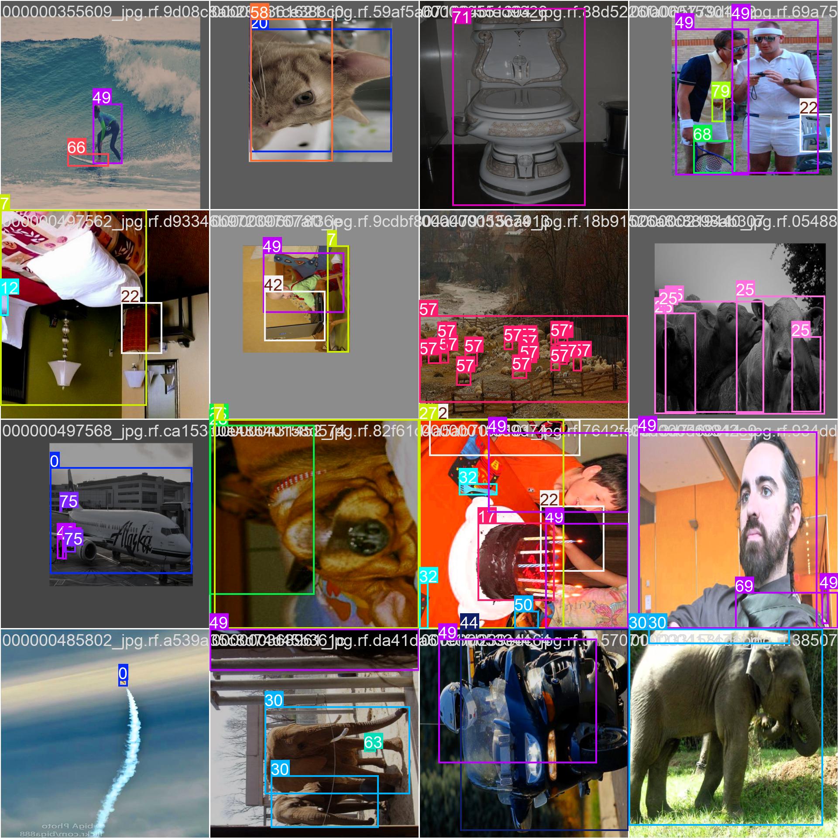
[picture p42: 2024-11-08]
Programming/train_test/runs/detect/train12/train_batch50961.jpg

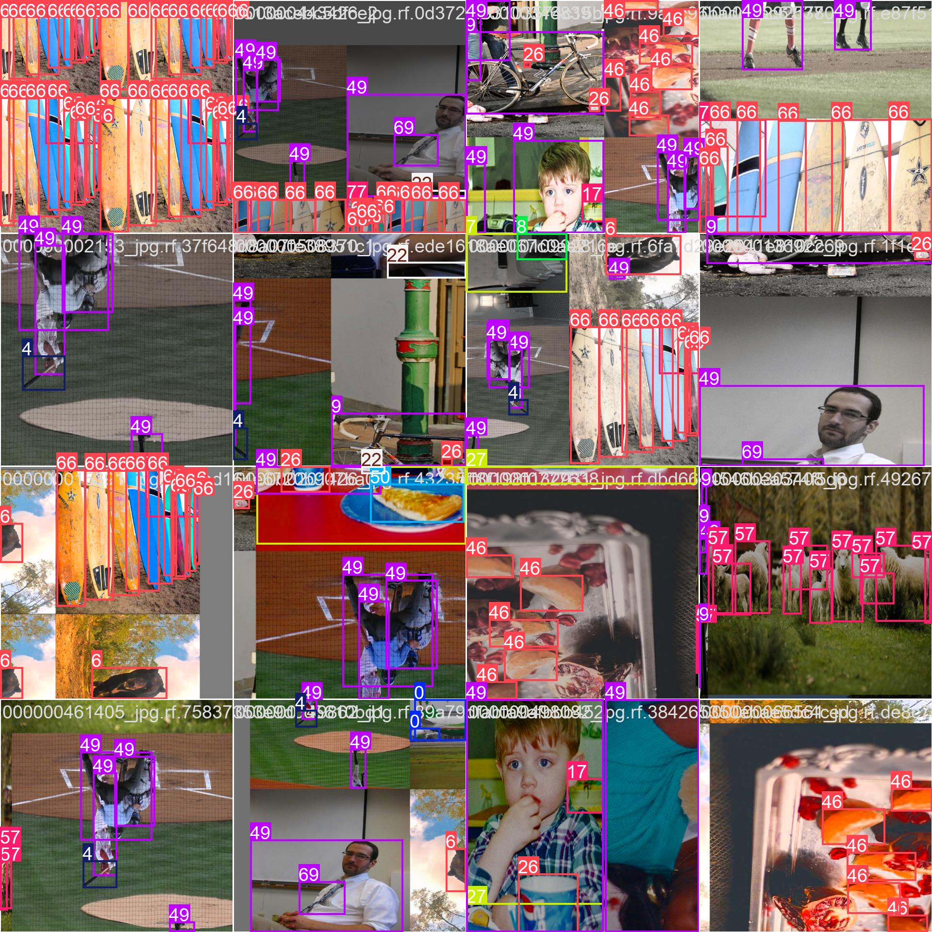
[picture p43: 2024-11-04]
Programming/train_test/runs/detect/train12/train_batch0.jpg

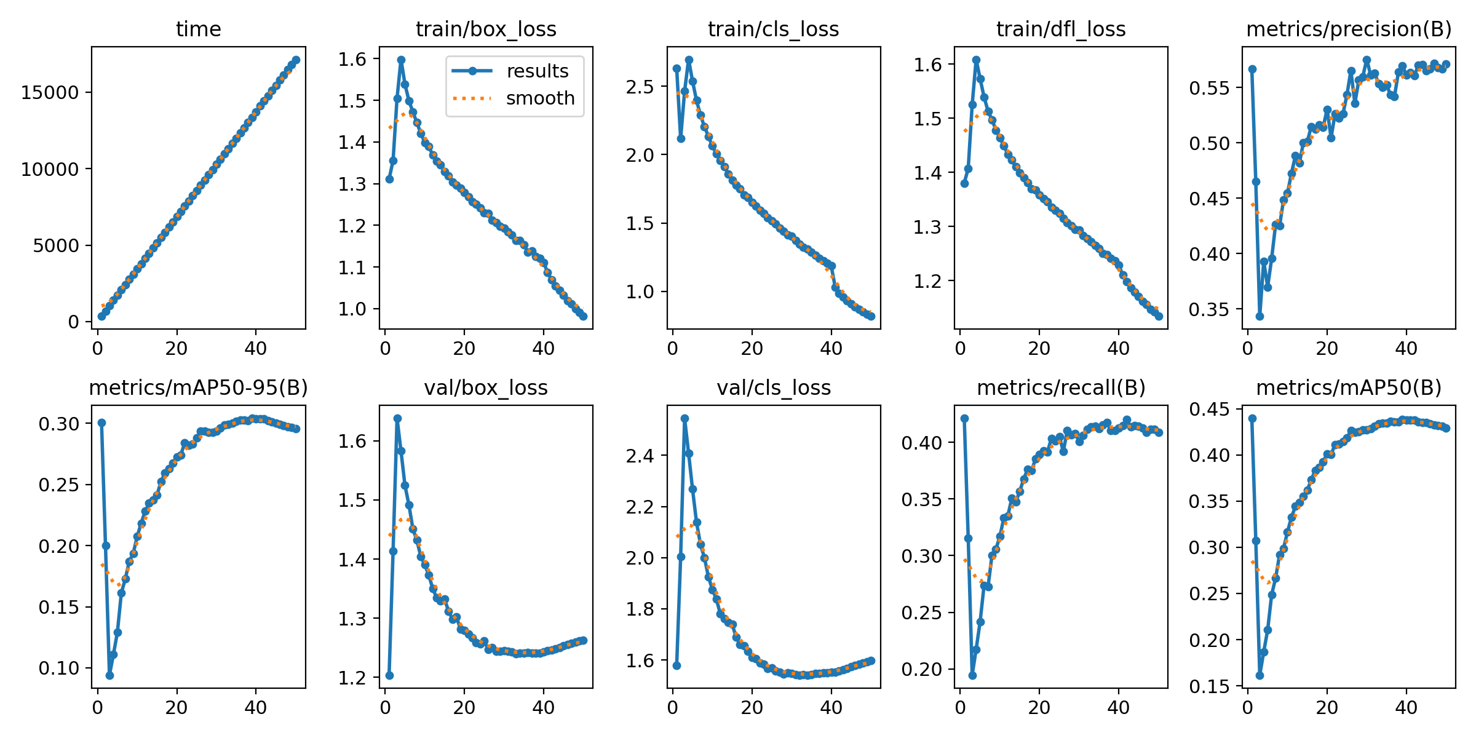
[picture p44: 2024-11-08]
Programming/train_test/runs/detect/train12/results.png

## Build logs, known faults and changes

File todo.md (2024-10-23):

- figure out what code is doing and read yolo documentation
- implement connection to matlab (working, but with python taking data from wrapper and sending over)
- try newer YOLO model (v8 only has pretrained models)
- Look into transfer learning for v8

- take photo of stuff in lab for base comparison for pretrained, custom trainied and freeze

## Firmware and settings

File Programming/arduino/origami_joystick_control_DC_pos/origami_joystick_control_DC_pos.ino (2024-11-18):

#include <Encoder.h>

#define x_val 4
#define y_val 5

#define M1_IN1_PIN 5
#define M1_IN2_PIN 6
#define M1_ENC_A 2
#define M1_ENC_B 8

#define M2_IN1_PIN 10
#define M2_IN2_PIN 11
#define M2_ENC_A 3
#define M2_ENC_B 9

Encoder enc_1(M1_ENC_A, M1_ENC_B);
Encoder enc_2(M2_ENC_A, M2_ENC_B);
// GLOBALS

double x = 512;
double y = 512;

double middle_y = 15;
double middle_x = 15;
double y_upper = middle_y*1.2;
double y_lower = middle_y*.8;
double x_upper = middle_x*1.2;
double x_lower = middle_x*.8;

int j = 0;

double FULL_TILT = 5;  //degrees. Need to find what is a good number for each jump
int PREV_DIR = 0;

int M1_PINS[2] = {M1_IN1_PIN, M1_IN2_PIN};
double M1_DES = 0;

int M2_PINS[2] = {M2_IN1_PIN, M2_IN2_PIN};
double M2_DES = 0;

int K_P = 10;
int K_I = 1;
int PID_TIME = 50;
unsigned long START = 0;
unsigned long LAST_TIME = 0;

volatile int M1_VEL = 0;
double M1_POS = 0;
volatile int M1_POS_LAST = 0;
volatile int M2_VEL = 0;
double M2_POS = 0;
volatile int M2_POS_LAST = 0;

class Motor_DC
{
  private:
      int in1;
      int in2;
      int encA;
      int encB;
      double k_p;
      double k_i;
      double interval;
      int error;
      double integral;
      unsigned long prev_time;
      int speed;
      double output;
      int pwm;
      double pos;
      double last_pos;
      int angle;
      double vel;
      unsigned long vel_time;
      unsigned long last_vel_time;

  public:
      Motor_DC(int pins[2], int k_p, int k_i){
          in1 = pins[0];
          in2 = pins[1];
          this->k_p = k_p;
          this->k_i = k_i;
          
      }
      void init(){
          pinMode(in1, OUTPUT);
          pinMode(in2, OUTPUT);
          //pinMode(encA, INPUT);
          //pinMode(encB, INPUT);
          
      }
      void pid(int des){
          interval = millis() - prev_time;
          prev_time = millis();
          
          error = des - pos;
          integral += error * interval;
          Serial.print("Actual: ");
          Serial.print(pos);
          Serial.print("Desired: ");
          Serial.print(des);
          Serial.print("Error: ");
          Serial.println(error);
          output = k_p*error + k_i*integral;
          
      }
      void forward(int pwm){
          analogWrite(in1, pwm);
          analogWrite(in2, 0);
          //Serial.println(" forwarded ");
      }
      void reverse(int pwm){
          analogWrite(in1, 0);
          analogWrite(in2, pwm);
          //Serial.println(" reversed ");
      }
      void stop(){
          analogWrite(in1, 0);
          analogWrite(in2, 0);
      }
      void go(){
          integral = 0;
          pwm = abs(output);
          //Serial.print("Output: ");
          //Serial.print(output);
          //Serial.print(" PWM: ");
          //Serial.print(pwm);
          if (output > 0){
              forward(min(pwm,255));
          }
          else if (output < 0){
              reverse(min(pwm,255)); // reverse should compress robot
          }
          else {
              stop();
          }
      }
      void update_pos(double posi){
          pos = posi;
          
      }
      void clear_integral(){
          integral = 0;
      }
      void print_info(){
          Serial.print("Output: ");
          Serial.print(output);
          Serial.print(" PWM: ");
          Serial.println(pwm);
      }

};

Motor_DC motor_1(M1_PINS, K_P, K_I);
Motor_DC motor_2(M2_PINS, K_P, K_I);

void setup() {

  motor_1.init();
  motor_2.init();
  motor_1.stop();
  motor_2.stop();
  delay(500); // Stop for 1 second
  
  Serial.begin(9600); // Initialize serial communication
  delay(500);
  read_joystick();
  print_xy();
  delay(500);
  init_joystick();
  Serial.println();
  Serial.print(middle_x);
  Serial.print(middle_y);
  Serial.println("done with setup");
  delay(1500);

}

void loop() {

  read_joystick();
  //print_xy();
  if (y > y_upper){
      Serial.println("decomp");
      check_dir(1);
      decompress();
      //Serial.print("M1 Pos: ");
      //Serial.print(get_m1_angle());
      //Serial.print(" Des pos: ");
      //Serial.println(M1_DES);
      // add way to ensure back to even tension when coming from turn back to compression
      START = millis();
      while (millis() - START < PID_TIME){
        do_pid();
        //motor_1.print_info();
        
      }
      
  }
  else if (y < y_lower){
      Serial.println("comp");
      check_dir(0);
      compress();
      //Serial.print("M1 Pos: ");
      //Serial.print(get_m1_angle());
      //Serial.print(" Des pos: ");
      //Serial.println(M1_DES);
      // add way to ensure back to even tension when coming from turn back to decompression
      START = millis();
      while (millis()-START < PID_TIME){
        do_pid();
        //motor_1.print_info();
      }
  }
  else{
      motor_1.stop();
      motor_2.stop();
      delay(PID_TIME);
  }
}

int read_joystick(){
    x = analogRead(x_val);
    y = analogRead(y_val);
}

double get_m1_angle(){
    long pos = enc_1.read();
    double angle = pos*180/(12*297.92);  //degree
    return angle;
}
double get_m2_angle(){
    long pos = enc_2.read();
    double angle = pos*180/(12*297.92);  //degree
    return angle;
}

void compress(){
    //Serial.print("y: ");
    //Serial.print(y);
    double y_norm = (y-middle_y)/middle_y;
    //Serial.print(" y_norm: ");
    //Serial.print(y_norm);
    
    double x_norm = (x-middle_x)/middle_x;
    double max_speed = abs(y_norm) * FULL_TILT;
    //double max_speed = 1;
    if (x_norm > 0.3){
        M1_DES += max_speed;
        M2_DES += (1-x_norm) * FULL_TILT;
    }
    else if (x_norm < -0.3){
        M1_DES += (1 - abs(x_norm)) * FULL_TILT;
        M2_DES += max_speed;
    }
    else{
        M1_DES += max_speed;
        M2_DES += max_speed;
    }
    
    //Serial.print(" compress: ");
    //Serial.println(max_speed);
}

void decompress(){
    double y_norm = (y-middle_y)/middle_y;
    double x_norm = (x-middle_x)/middle_x;
    double max_speed = -abs(y_norm) * FULL_TILT;
    //double max_speed = -1;
    if (x_norm > 0.3){
        M1_DES += max_speed;
        double added = -abs(y_norm)*x_norm * FULL_TILT;
        Serial.print("Added: ");
        Serial.println(added);
        M2_DES += (1-x_norm) * max_speed;
    }
    else if (x_norm < -0.3){
        double added = -abs(y_norm)*x_norm * FULL_TILT;
        Serial.print("Added: ");
        Serial.println(added);
        M1_DES += (1-abs(x_norm)) * max_speed;
        M2_DES += max_speed;
    }
    else{
        M1_DES += max_speed;
        M2_DES += max_speed;
    }
    //Serial.print("y: ");
    //Serial.print(y);
    //Serial.print(" y_norm: ");
    //Serial.print(y_norm);
    Serial.print(" decompress: ");
    Serial.println(max_speed);

}
void print_xy(){
  Serial.print("x = ");
  Serial.print(x);
  Serial.print(" y = ");
  Serial.print(y);
  Serial.println();
}
void do_pid(){
  M1_POS = get_m1_angle();
  M2_POS = get_m2_angle();
  Serial.print("M1 Angle: ");
  Serial.print(M1_POS);
  Serial.print("M2 Angle: ");
  Serial.println(M2_POS);
  motor_1.update_pos(M1_POS);
  motor_2.update_pos(M2_POS);
  Serial.print("M1, M2 DES:");
  Serial.print(M1_DES);
  Serial.print(", ");
  Serial.println(M2_DES);
  motor_1.pid(M1_DES);
  motor_2.pid(M2_DES);
  motor_1.go();
  motor_2.go();
  delay(5);
}
void check_dir(int dir){
  
  if (dir != PREV_DIR){
    Serial.print(dir);
    Serial.println(", in check dir");
    motor_1.clear_integral();
    motor_2.clear_integral();
    get_m1_angle();
    get_m2_angle();
    if (dir == 1){
      M1_DES = -1*abs(M1_POS);
      M2_DES = -1*abs(M1_POS);
    }
    else {
      M1_DES = 1*abs(M1_POS);
      M2_DES = 1*abs(M1_POS);
    }
    //M1_DES = M1_POS;
    //M2_DES = M2_POS;
    //Serial.print("M1_POS");
    //Serial.print(M1_POS);
    Serial.print("M1_DES");
    Serial.println(M1_DES);

    PREV_DIR = dir;
  }
}
void init_joystick(){
  middle_x = x;
  middle_y = y;
  y_upper = middle_y*1.2;
  y_lower = middle_y*.8;
  x_upper = middle_x*1.2;
  x_lower = middle_x*.8;
}

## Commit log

2024-09-30 Create Excel Time Sheet.xlsx
    [Excel Time Sheet.xlsx]
2024-09-30 create time sheet and new ideas or knowledge
    [Excel Time Sheet.xlsx]
2024-09-30 Update Excel Time Sheet.xlsx
    [Excel Time Sheet.xlsx]
2024-09-30 add cv_test.py and update
    [Excel Time Sheet.xlsx]
2024-10-01 updating time_sheet and update detection test
    [Excel Time Sheet.xlsx]
2024-10-06 implement v8
    [Excel Time Sheet.xlsx]
2024-10-07 add matlab support
    [Excel Time Sheet.xlsx]
2024-10-11 add transfer learning stuff
    [Excel Time Sheet.xlsx]
2024-10-11 add photos of robot arm
2024-10-11 update timesheet
    [Excel Time Sheet.xlsx]
2024-10-12 trying roboflow and training v8 model
    [Excel Time Sheet.xlsx, results.csv]
2024-10-13 new training data, works for specific object detection
    [Excel Time Sheet.xlsx, results.csv]
2024-10-13 add cad, new friction idea
    [Directional Friction Flexure.sldprt, Directional Friction Pad.sldprt, Excel Time Sheet.xlsx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]
2024-10-13 add solidworks photo to log
    [Excel Time Sheet.xlsx, Mount Clamp^Worm_Robot.STL, Servo Mount Clamp Test.SLDPRT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]
2024-10-13 fixing spacing on clamp
    [Excel Time Sheet.xlsx, Mount Clamp^Worm_Robot.STL, Servo Mount Clamp Test.SLDPRT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]
2024-10-14 friction pads and new clamp walls
    [Directional Friction Flexure.sldprt, Directional Friction Flexure_less.SLDPRT, Directional Friction Flexure_less.STL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]
2024-10-15 update clamp
    [Directional Friction Flexure_less.SLDPRT, Excel Time Sheet.xlsx, Mount Clamp Left^Worm_Robot.STL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]
2024-10-16 make pulley horn
    [Excel Time Sheet.xlsx, FS09R_Servo_Motor.SLDPRT, Pulley Horn^Worm_Robot.STL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]
2024-10-19 new cad stuff
    [Directional Friction Flexure_less.STL, Excel Time Sheet.xlsx, Mount Clamp Left^Worm_Robot.STL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]
2024-10-20 new designs
    [Excel Time Sheet.xlsx, Pulley Horn^Worm_Robot.SLDPRT, Pulley Horn^Worm_Robot.STL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]
2024-10-21 update stuff
    [Excel Time Sheet.xlsx, Servo Motor Mount.STL, Servo Motor Mounts.STL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]
2024-10-21 add cad folders
    [Directional Friction Flexure.sldprt, Directional Friction Flexure_less.SLDPRT, Directional Friction Flexure_less.STL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]
2024-10-22 add log photos
    [Excel Time Sheet.xlsx]
2024-10-24 add comparison images
    [Excel Time Sheet.xlsx]
2024-10-27 doing stuff
    [Excel Time Sheet.xlsx]
2024-11-03 add arduino scripts
2024-11-04 add a whole bunch
    [Excel Time Sheet.xlsx, Gear box^Worm_Robot.STL, Joystick Base^Worm_Robot.STL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]
2024-11-06 create new friction pads
    [Excel Time Sheet.xlsx, Matty Light Mount.SLDPRT, Worm_Robot.SLDASM]
2024-11-08 add train results from 50
    [results.csv]
2024-11-08 add new friction pad
    [Excel Time Sheet.xlsx, Worm_Robot.SLDASM]
2024-11-09 adding stuff
    [DC Clamp^Worm_Robot.STL, DC Motor Mount.SLDPRT, DC Motor Mount.STL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]
2024-11-11 fix and add
    [DC Motor Mount.SLDPRT, DC Motor Mount.STL, DC Pulley.SLDPRT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]
2024-11-11 create dc control script
    [Excel Time Sheet.xlsx]
2024-11-12 update arduino code
2024-11-12 add log entry and update time
    [Excel Time Sheet.xlsx]
2024-11-13 add script to pos pid
    [Excel Time Sheet.xlsx]
2024-11-13 adjust motor mount
    [DC Motor Mount.SLDPRT, DC Motor Mount.STL, Excel Time Sheet.xlsx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]
2024-11-15 update time
    [Excel Time Sheet.xlsx]
2024-11-18 add flow
    [Excel Time Sheet.xlsx]
2024-11-18 add vel controller
    [Excel Time Sheet.xlsx]
2024-12-04 friction pad stuff
    [Excel Time Sheet.xlsx, Friction_straightangled_long_15_4^Worm_Robot.STL, Friction_straightangled_long_25_4.5^Worm_Robot.STL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]
